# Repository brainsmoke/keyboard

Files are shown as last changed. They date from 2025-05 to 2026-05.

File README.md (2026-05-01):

# A numpad-less keyboard with back lighting

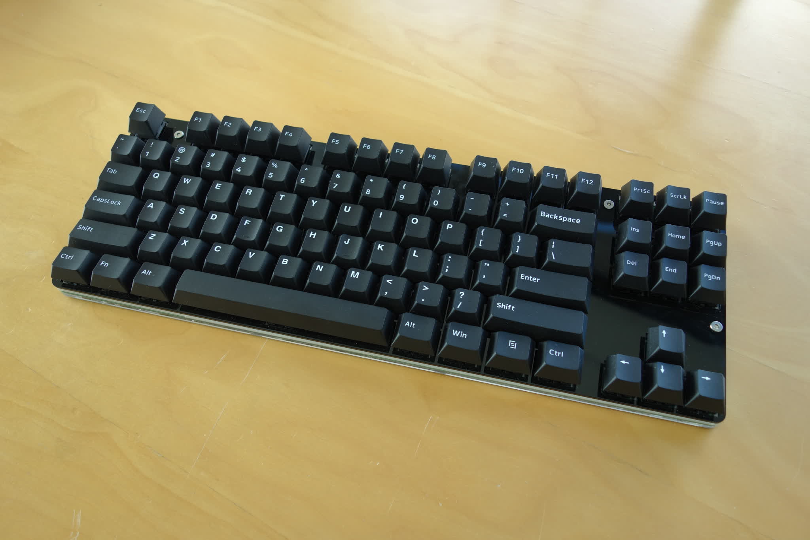
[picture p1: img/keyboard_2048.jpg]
Photo of the completed keyboard, an '80%' layout, the PCB is sandwiched in between a few layers of acrylic


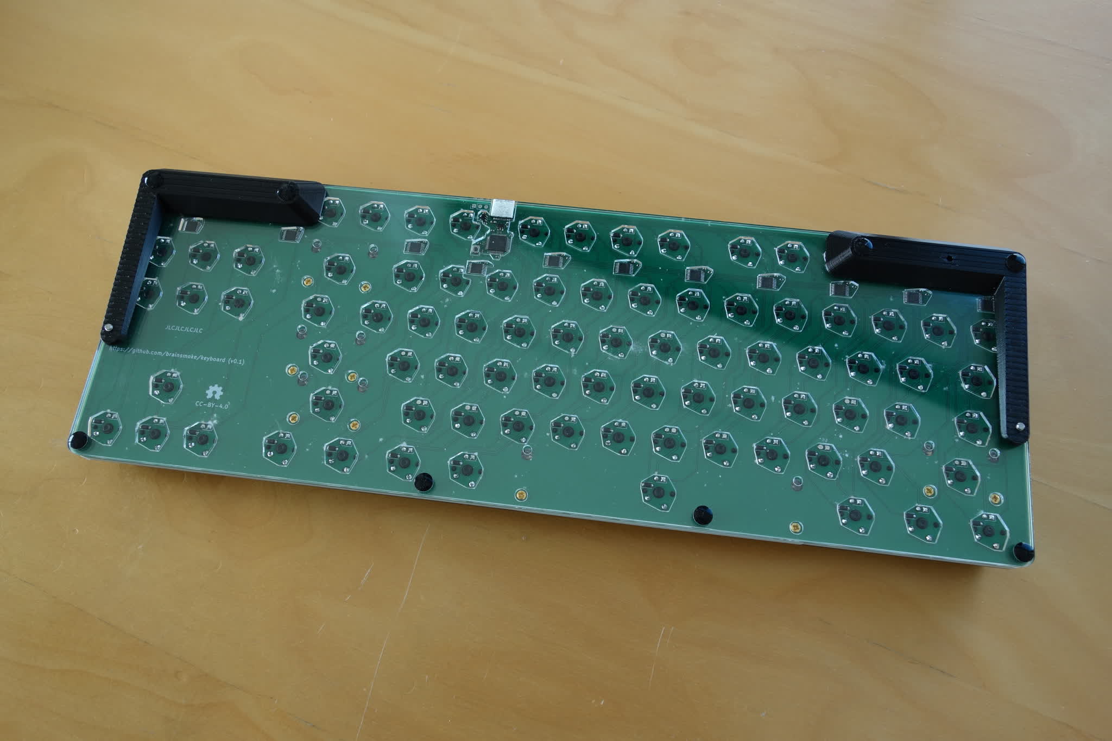
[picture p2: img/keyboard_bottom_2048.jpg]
Photo of the bottom side of the keyboard, the bottom is covered in transparant acrylic, exposing the circuit & chips


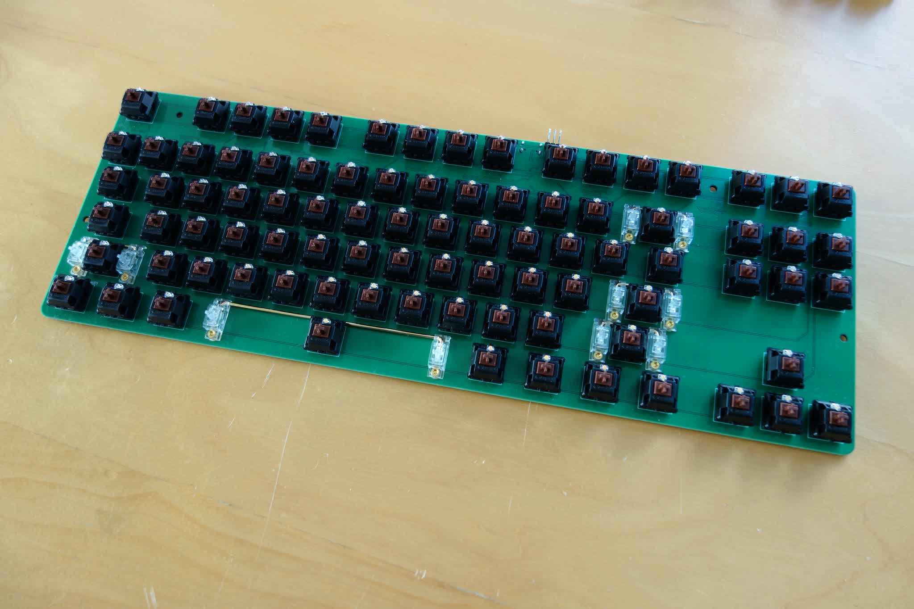
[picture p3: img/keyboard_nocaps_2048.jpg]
Photo of the keyboard without keycaps, exposing the cherry style keys


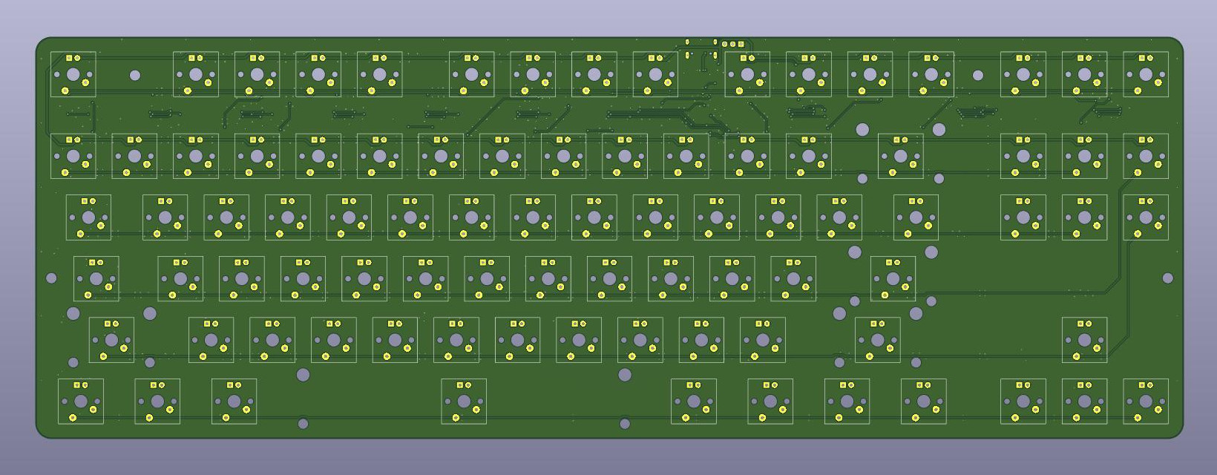
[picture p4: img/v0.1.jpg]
Image of a keyboard PCB


TODO: find keycaps which look good with AND without backlight

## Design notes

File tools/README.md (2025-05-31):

```
apt install python3-venv
python3 -m venv --system-site-packages venv ;. venv/bin/activate
pip3 install kicad-python

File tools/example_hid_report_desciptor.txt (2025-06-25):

Usage Page (Generic Desktop)
Usage (Keypad)
Collection (Application)
Usage Page (Keyboard)

Usage (Generic Desktop, System Sleep)
Usage (Generic Desktop, System Wake Up)
Usage (Generic Desktop, System Power Down)
Usage (Generic Desktop, System Warm Restart)

Usage (Consumer, Play)
Usage (Consumer, Pause)
Usage (Consumer, Stop)
Usage (Consumer, Record)

Usage (Consumer, Rewind)
Usage (Consumer, Fast Forward)
Usage (Consumer, Scan Previous Track)
Usage (Consumer, Scan Next Track)

Usage (Keyboard, Volume Down)
Usage (Keyboard, Volume Up)
Usage (Consumer, AL Calculator)
Usage (Keyboard, 0x04)

Report Size (1)
Report Count (16)
Input (Data, Variable, Absolute)

Report Size (8)
Report Count (1)
Input (Constant)

End Collection

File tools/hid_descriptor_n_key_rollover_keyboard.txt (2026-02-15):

Usage Page (Generic Desktop)
Usage (Keyboard)
Collection (Application)
  Report Size (1)
  Report Count (8)
  Usage Page (Keyboard)
  Usage Minimum (224)
  Usage Maximum (231)
  Logical Minimum (0)
  Logical Maximum (1)
  Input (Data, Variable, Absolute)
  Report Count (1)
  Report Size (8)
  Input (Constant)
  Report Count (5)
  Report Size (1)
  Usage Page (LED)
  Usage Minimum (1)
  Usage Maximum (5)
  Output (Data, Variable, Absolute)
  Report Count (1)
  Report Size (3)
  Output (Constant)
  Report Count (6)
  Report Size (8)
#  Logical Minimum (0)
#  Logical Maximum(255)
#  Usage Page (Keyboard)
#  Usage Minimum (0)
#  Usage Maximum (255)
#  Input (Data, Array)
  Input (Constant)
  Usage Page (Keyboard)
  Report Size (1)
  Report Count (79)
  Usage Minimum (4)
  Usage Maximum (82)
  Input (Data, Variable, Absolute)
End Collection

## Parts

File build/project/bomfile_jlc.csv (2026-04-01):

Comment | Designator | Footprint | JLCPCB Part #
1uF | C1,C2,C3,C4,C10 | Capacitor_SMD:C_0402_1005Metric | C52923
100nF | C5,C6,C7,C8,C9,C11,C12,C13,C14,C15,C16,C17 | Capacitor_SMD:C_0402_1005Metric | C1525
d_0,d_1,d_2,d_3,d_4,d_5,d_6,d_7,d_8,d_9,d_a,d_alt,d_altgr,d_b,d_backslash,d_backspace,d_c,d_capslock,d_closebracket,d_comma,d_d,d_delete,d_dot,d_down,d_e,d_end,d_enter,d_equals,d_esc,d_f,d_f1,d_f10,d_f11,d_f12,d_f2,d_f3,d_f4,d_f5,d_f6,d_f7,d_f8,d_f9,d_fn,d_g,d_h,d_home,d_i,d_insert,d_j,d_k,d_l,d_left,d_leftcontrol,d_leftshift,d_m,d_menu,d_minus,d_n,d_o,d_openbracket,d_p,d_pagedown,d_pageup,d_pause,d_printscreen,d_q,d_quote,d_r,d_right,d_rightcontrol,d_rightshift,d_s,d_scrollock,d_semicolon,d_slash,d_space,d_t,d_tab,d_tilde,d_u,d_up,d_v,d_w,d_win,d_x,d_y,d_z | D1,D2,D3,D4,D5,D6,D7,D8,D9,D10,D11,D12,D13,D14,D15,D16,D17,D18,D19,D20,D21,D22,D23,D24,D25,D26,D27,D28,D29,D30,D31,D32,D33,D34,D35,D36,D37,D38,D39,D40,D41,D42,D43,D44,D45,D46,D47,D48,D49,D50,D51,D52,D53,D54,D55,D56,D57,D58,D59,D60,D61,D62,D63,D64,D65,D66,D67,D68,D69,D70,D71,D72,D73,D74,D75,D76,D77,D78,D79,D80,D81,D82,D83,D84,D85,D86,D87 | Diode_SMD:D_SOD-123 | C81598
USB_C_Receptacle_USB2.0 | J1 | footprints:USB_C_Receptacle_HRO_TYPE-C-31-M-12 | C165948
100k | R1,R4 | Resistor_SMD:R_0402_1005Metric | C25741
5k1,REXT_0,REXT_1,REXT_10,REXT_2,REXT_3,REXT_4,REXT_5,REXT_6,REXT_7,REXT_8,REXT_9 | R2,R3,R5,R6,R7,R8,R9,R10,R11,R12,R13,R14,R15 | Resistor_SMD:R_0402_1005Metric | C25905
SW_SPST | SW88 | Button_Switch_SMD:SW_Push_1P1T_NO_CK_KMR2 | C318893
USBLC6-2SC6 | U1 | Package_TO_SOT_SMD:SOT-23-6 | C7519
STM32F072C8Tx | U2 | Package_QFP:LQFP-48_7x7mm_P0.5mm | C81720
AP2112K-3.3 | U3 | Package_TO_SOT_SMD:SOT-23-5 | C51118
TLC5916_0,TLC5916_1,TLC5916_10,TLC5916_2,TLC5916_3,TLC5916_4,TLC5916_5,TLC5916_6,TLC5916_7,TLC5916_8,TLC5916_9 | U4,U5,U6,U7,U8,U9,U10,U11,U12,U13,U14 | Package_SO:TSSOP-16_4.4x5mm_P0.65mm | C2678539

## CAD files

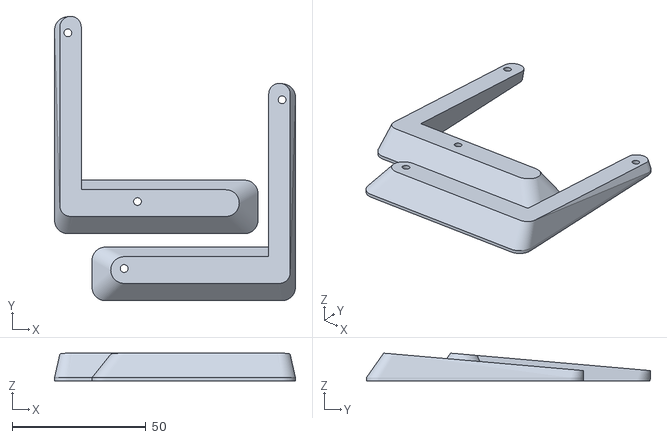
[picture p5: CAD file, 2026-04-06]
case/feet_upside_down.stl
90.0 x 106.2 x 10.4

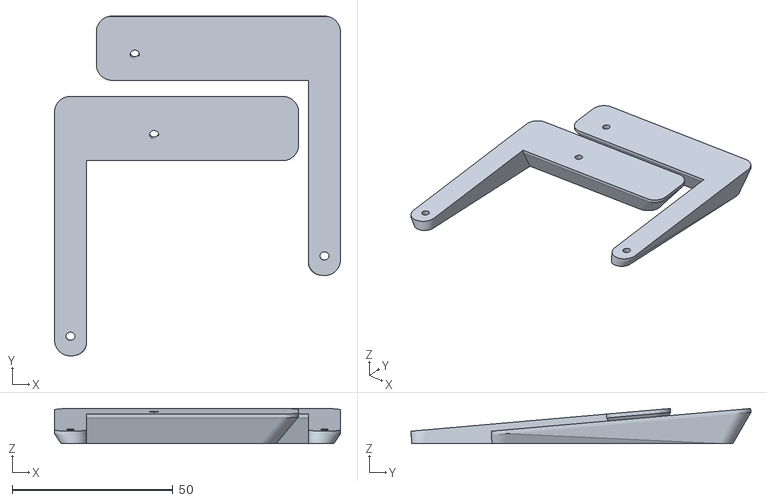
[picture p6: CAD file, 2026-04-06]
case/feet_print_right_side_up.stl
89.0 x 105.8 x 10.9

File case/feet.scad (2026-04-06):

e=.001;
$fn=48;
padding=5;

dim = [ 357, 125, 10 ] ;

holes = [ [31, dim.y-12], [dim.x-64, dim.y-12], [ 5, 50 ], [dim.x-5, 50 ] ] ;

r = 5;

bottom = 1.2;
screw_hole_d = 2.9;

angle = 5;

module do_center(dim, center)
{
    if (center)
        translate(-dim/2)
            children();
    else
        children();
}
 
module rounded_box(dim, r, center=false)
{
    do_center(dim, center)
    hull()
    {
        for (x=[r,dim.x-r])
        for (y=[r,dim.y-r])
        translate([x,y,0])
        cylinder(h=dim.z,r=r);
    }
}

module preview()
{
	if ($preview) children();
}


module at_holes()
{
	for (pos=holes)
        translate([pos.x, pos.y, 0])
            children();
}

module reflect_x(x)
{
	translate([x,0,0])
	scale([-1,1,1])
	translate([-x,0,0])
	children();
}

module mirror_x(x)
{
	children();
	reflect_x(x)
	children();
}


module feet()
{

	difference()
	{
	union()
	{
		mirror_x(dim.x/2)
		hull()
		{
		rotate([-angle,0,0])
		translate([2,dim.y-16,0])
		rounded_box([67, 10, bottom], 5);
		translate([0,dim.y-20,-bottom])
		rounded_box([76, 20, bottom], r);
		}

		mirror_x(dim.x/2)
		hull()
		{
		rotate([-angle,0,0])
		translate([2,dim.y-81,0])
		rounded_box([8, 75, bottom], 4);
		translate([0,dim.y-81,-bottom])
		rounded_box([10, 81, bottom], r);
		}
	}

	at_holes() translate([0,0,-20+e]) cylinder(d=screw_hole_d, h=20);
	}
}

module left_foot()
{
	intersection()
	{
	translate([-5,-5,-25])
	cube([dim.x/2+5,dim.y+10, 30]);
	feet();
	}
}


module right_foot()
{
	intersection()
	{
	reflect_x(dim.x/2)
	translate([-5,-5,-25])
	cube([dim.x/2+5,dim.y+10, 30]);
	feet();
	}
}

preview()
{
left_foot();
right_foot();
}

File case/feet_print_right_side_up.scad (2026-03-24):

use <feet.scad>;


translate([0,-43,0])
{
rotate( [5,0,0] )
left_foot();

translate([-268,25,0])
rotate( [5,0,0] )
right_foot();
}

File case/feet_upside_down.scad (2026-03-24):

use <feet.scad>;

translate([0,150,0])
rotate([180,0,0])
{
left_foot();

translate([-267,25,0])
right_foot();
}

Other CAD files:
case/usb.scad

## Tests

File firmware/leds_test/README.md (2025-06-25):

# idoing pcb tests before I solder all my mx keys

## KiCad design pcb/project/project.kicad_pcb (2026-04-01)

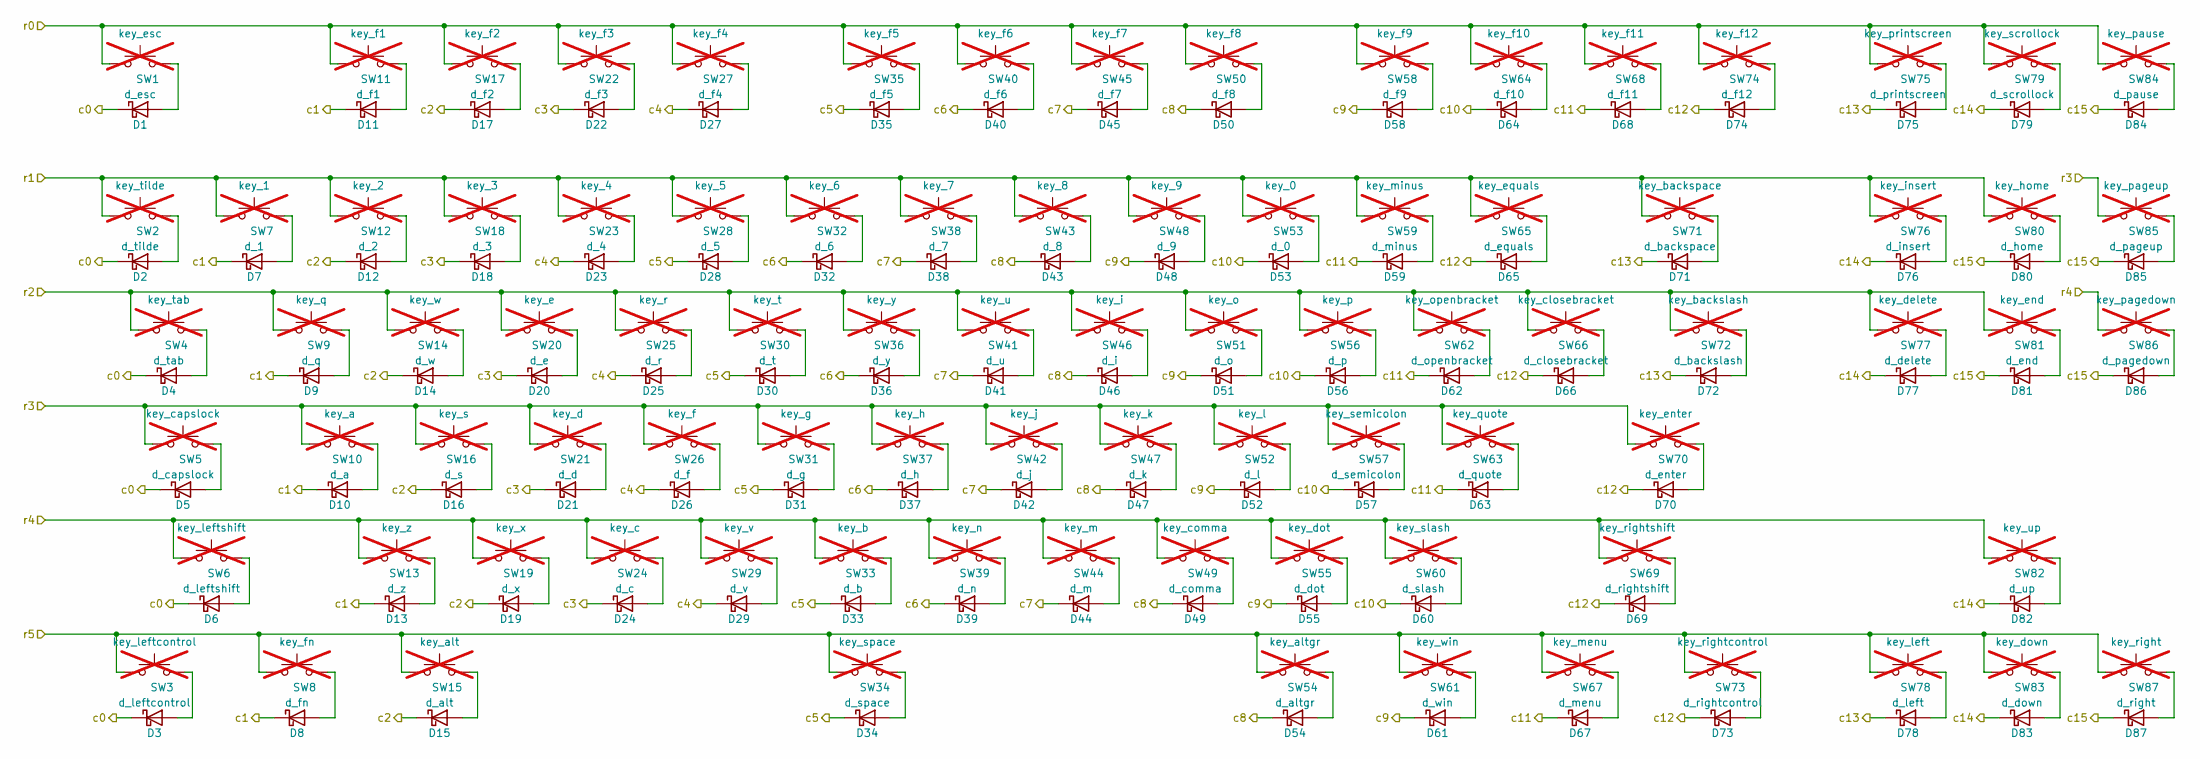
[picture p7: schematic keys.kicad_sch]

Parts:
D1: d_esc; D_SOD-123; LCSC C81598
D2: d_tilde; D_SOD-123; LCSC C81598
D3: d_leftcontrol; D_SOD-123; LCSC C81598
D4: d_tab; D_SOD-123; LCSC C81598
D5: d_capslock; D_SOD-123; LCSC C81598
D6: d_leftshift; D_SOD-123; LCSC C81598
D7: d_1; D_SOD-123; LCSC C81598
D8: d_fn; D_SOD-123; LCSC C81598
D9: d_q; D_SOD-123; LCSC C81598
D10: d_a; D_SOD-123; LCSC C81598
D11: d_f1; D_SOD-123; LCSC C81598
D12: d_2; D_SOD-123; LCSC C81598
D13: d_z; D_SOD-123; LCSC C81598
D14: d_w; D_SOD-123; LCSC C81598
D15: d_alt; D_SOD-123; LCSC C81598
D16: d_s; D_SOD-123; LCSC C81598
D17: d_f2; D_SOD-123; LCSC C81598
D18: d_3; D_SOD-123; LCSC C81598
D19: d_x; D_SOD-123; LCSC C81598
D20: d_e; D_SOD-123; LCSC C81598
D21: d_d; D_SOD-123; LCSC C81598
D22: d_f3; D_SOD-123; LCSC C81598
D23: d_4; D_SOD-123; LCSC C81598
D24: d_c; D_SOD-123; LCSC C81598
D25: d_r; D_SOD-123; LCSC C81598
D26: d_f; D_SOD-123; LCSC C81598
D27: d_f4; D_SOD-123; LCSC C81598
D28: d_5; D_SOD-123; LCSC C81598
D29: d_v; D_SOD-123; LCSC C81598
D30: d_t; D_SOD-123; LCSC C81598
D31: d_g; D_SOD-123; LCSC C81598
D32: d_6; D_SOD-123; LCSC C81598
D33: d_b; D_SOD-123; LCSC C81598
D34: d_space; D_SOD-123; LCSC C81598
D35: d_f5; D_SOD-123; LCSC C81598
D36: d_y; D_SOD-123; LCSC C81598
D37: d_h; D_SOD-123; LCSC C81598
D38: d_7; D_SOD-123; LCSC C81598
D39: d_n; D_SOD-123; LCSC C81598
D40: d_f6; D_SOD-123; LCSC C81598
D41: d_u; D_SOD-123; LCSC C81598
D42: d_j; D_SOD-123; LCSC C81598
D43: d_8; D_SOD-123; LCSC C81598
D44: d_m; D_SOD-123; LCSC C81598
D45: d_f7; D_SOD-123; LCSC C81598
D46: d_i; D_SOD-123; LCSC C81598
D47: d_k; D_SOD-123; LCSC C81598
D48: d_9; D_SOD-123; LCSC C81598
D49: d_comma; D_SOD-123; LCSC C81598
D50: d_f8; D_SOD-123; LCSC C81598
D51: d_o; D_SOD-123; LCSC C81598
D52: d_l; D_SOD-123; LCSC C81598
D53: d_0; D_SOD-123; LCSC C81598
D54: d_altgr; D_SOD-123; LCSC C81598
D55: d_dot; D_SOD-123; LCSC C81598
D56: d_p; D_SOD-123; LCSC C81598
D57: d_semicolon; D_SOD-123; LCSC C81598
D58: d_f9; D_SOD-123; LCSC C81598
D59: d_minus; D_SOD-123; LCSC C81598
D60: d_slash; D_SOD-123; LCSC C81598
D61: d_win; D_SOD-123; LCSC C81598
D62: d_openbracket; D_SOD-123; LCSC C81598
D63: d_quote; D_SOD-123; LCSC C81598
D64: d_f10; D_SOD-123; LCSC C81598
D65: d_equals; D_SOD-123; LCSC C81598
D66: d_closebracket; D_SOD-123; LCSC C81598
D67: d_menu; D_SOD-123; LCSC C81598
D68: d_f11; D_SOD-123; LCSC C81598
D69: d_rightshift; D_SOD-123; LCSC C81598
D70: d_enter; D_SOD-123; LCSC C81598
D71: d_backspace; D_SOD-123; LCSC C81598
D72: d_backslash; D_SOD-123; LCSC C81598
D73: d_rightcontrol; D_SOD-123; LCSC C81598
D74: d_f12; D_SOD-123; LCSC C81598
D75: d_printscreen; D_SOD-123; LCSC C81598
D76: d_insert; D_SOD-123; LCSC C81598
D77: d_delete; D_SOD-123; LCSC C81598
D78: d_left; D_SOD-123; LCSC C81598
D79: d_scrollock; D_SOD-123; LCSC C81598
D80: d_home; D_SOD-123; LCSC C81598
D81: d_end; D_SOD-123; LCSC C81598
D82: d_up; D_SOD-123; LCSC C81598
D83: d_down; D_SOD-123; LCSC C81598
D84: d_pause; D_SOD-123; LCSC C81598
D85: d_pageup; D_SOD-123; LCSC C81598
D86: d_pagedown; D_SOD-123; LCSC C81598
D87: d_right; D_SOD-123; LCSC C81598
SW1: key_esc; SW_Cherry_MX_1.00u_PCB; not fitted
SW2: key_tilde; SW_Cherry_MX_1.00u_PCB; not fitted
SW3: key_leftcontrol; SW_Cherry_MX_1.25u_PCB; not fitted
SW4: key_tab; SW_Cherry_MX_1.50u_PCB; not fitted
SW5: key_capslock; SW_Cherry_MX_1.75u_PCB; not fitted
SW6: key_leftshift; SW_Cherry_MX_2.25u_PCB; not fitted
SW7: key_1; SW_Cherry_MX_1.00u_PCB; not fitted
SW8: key_fn; SW_Cherry_MX_1.25u_PCB; not fitted
SW9: key_q; SW_Cherry_MX_1.00u_PCB; not fitted
SW10: key_a; SW_Cherry_MX_1.00u_PCB; not fitted
SW11: key_f1; SW_Cherry_MX_1.00u_PCB; not fitted
SW12: key_2; SW_Cherry_MX_1.00u_PCB; not fitted
SW13: key_z; SW_Cherry_MX_1.00u_PCB; not fitted
SW14: key_w; SW_Cherry_MX_1.00u_PCB; not fitted
SW15: key_alt; SW_Cherry_MX_1.25u_PCB; not fitted
SW16: key_s; SW_Cherry_MX_1.00u_PCB; not fitted
SW17: key_f2; SW_Cherry_MX_1.00u_PCB; not fitted
SW18: key_3; SW_Cherry_MX_1.00u_PCB; not fitted
SW19: key_x; SW_Cherry_MX_1.00u_PCB; not fitted
SW20: key_e; SW_Cherry_MX_1.00u_PCB; not fitted
SW21: key_d; SW_Cherry_MX_1.00u_PCB; not fitted
SW22: key_f3; SW_Cherry_MX_1.00u_PCB; not fitted
SW23: key_4; SW_Cherry_MX_1.00u_PCB; not fitted
SW24: key_c; SW_Cherry_MX_1.00u_PCB; not fitted
SW25: key_r; SW_Cherry_MX_1.00u_PCB; not fitted
SW26: key_f; SW_Cherry_MX_1.00u_PCB; not fitted
SW27: key_f4; SW_Cherry_MX_1.00u_PCB; not fitted
SW28: key_5; SW_Cherry_MX_1.00u_PCB; not fitted
SW29: key_v; SW_Cherry_MX_1.00u_PCB; not fitted
SW30: key_t; SW_Cherry_MX_1.00u_PCB; not fitted
SW31: key_g; SW_Cherry_MX_1.00u_PCB; not fitted
SW32: key_6; SW_Cherry_MX_1.00u_PCB; not fitted
SW33: key_b; SW_Cherry_MX_1.00u_PCB; not fitted
SW34: key_space; SW_Cherry_MX_6.25u_PCB; not fitted
SW35: key_f5; SW_Cherry_MX_1.00u_PCB; not fitted
SW36: key_y; SW_Cherry_MX_1.00u_PCB; not fitted
SW37: key_h; SW_Cherry_MX_1.00u_PCB; not fitted
SW38: key_7; SW_Cherry_MX_1.00u_PCB; not fitted
SW39: key_n; SW_Cherry_MX_1.00u_PCB; not fitted
SW40: key_f6; SW_Cherry_MX_1.00u_PCB; not fitted
SW41: key_u; SW_Cherry_MX_1.00u_PCB; not fitted
SW42: key_j; SW_Cherry_MX_1.00u_PCB; not fitted
SW43: key_8; SW_Cherry_MX_1.00u_PCB; not fitted
SW44: key_m; SW_Cherry_MX_1.00u_PCB; not fitted
SW45: key_f7; SW_Cherry_MX_1.00u_PCB; not fitted
SW46: key_i; SW_Cherry_MX_1.00u_PCB; not fitted
SW47: key_k; SW_Cherry_MX_1.00u_PCB; not fitted
SW48: key_9; SW_Cherry_MX_1.00u_PCB; not fitted
SW49: key_comma; SW_Cherry_MX_1.00u_PCB; not fitted
SW50: key_f8; SW_Cherry_MX_1.00u_PCB; not fitted
SW51: key_o; SW_Cherry_MX_1.00u_PCB; not fitted
SW52: key_l; SW_Cherry_MX_1.00u_PCB; not fitted
SW53: key_0; SW_Cherry_MX_1.00u_PCB; not fitted
SW54: key_altgr; SW_Cherry_MX_1.25u_PCB; not fitted
SW55: key_dot; SW_Cherry_MX_1.00u_PCB; not fitted
SW56: key_p; SW_Cherry_MX_1.00u_PCB; not fitted
SW57: key_semicolon; SW_Cherry_MX_1.00u_PCB; not fitted
SW58: key_f9; SW_Cherry_MX_1.00u_PCB; not fitted
SW59: key_minus; SW_Cherry_MX_1.00u_PCB; not fitted
SW60: key_slash; SW_Cherry_MX_1.00u_PCB; not fitted
SW61: key_win; SW_Cherry_MX_1.25u_PCB; not fitted
SW62: key_openbracket; SW_Cherry_MX_1.00u_PCB; not fitted
SW63: key_quote; SW_Cherry_MX_1.00u_PCB; not fitted
SW64: key_f10; SW_Cherry_MX_1.00u_PCB; not fitted
SW65: key_equals; SW_Cherry_MX_1.00u_PCB; not fitted
SW66: key_closebracket; SW_Cherry_MX_1.00u_PCB; not fitted
SW67: key_menu; SW_Cherry_MX_1.25u_PCB; not fitted
SW68: key_f11; SW_Cherry_MX_1.00u_PCB; not fitted
SW69: key_rightshift; SW_Cherry_MX_2.75u_PCB; not fitted
SW70: key_enter; SW_Cherry_MX_2.25u_PCB; not fitted
SW71: key_backspace; SW_Cherry_MX_2.00u_PCB; not fitted
SW72: key_backslash; SW_Cherry_MX_1.50u_PCB; not fitted
SW73: key_rightcontrol; SW_Cherry_MX_1.25u_PCB; not fitted
SW74: key_f12; SW_Cherry_MX_1.00u_PCB; not fitted
SW75: key_printscreen; SW_Cherry_MX_1.00u_PCB; not fitted
SW76: key_insert; SW_Cherry_MX_1.00u_PCB; not fitted
SW77: key_delete; SW_Cherry_MX_1.00u_PCB; not fitted
SW78: key_left; SW_Cherry_MX_1.00u_PCB; not fitted
SW79: key_scrollock; SW_Cherry_MX_1.00u_PCB; not fitted
SW80: key_home; SW_Cherry_MX_1.00u_PCB; not fitted
SW81: key_end; SW_Cherry_MX_1.00u_PCB; not fitted
SW82: key_up; SW_Cherry_MX_1.00u_PCB; not fitted
SW83: key_down; SW_Cherry_MX_1.00u_PCB; not fitted
SW84: key_pause; SW_Cherry_MX_1.00u_PCB; not fitted
SW85: key_pageup; SW_Cherry_MX_1.00u_PCB; not fitted
SW86: key_pagedown; SW_Cherry_MX_1.00u_PCB; not fitted
SW87: key_right; SW_Cherry_MX_1.00u_PCB; not fitted

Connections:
/C0: D1.1 (K), D2.1 (K), D3.1 (K), D4.1 (K), D5.1 (K), D6.1 (K); also elsewhere on the board
/C1: D7.1 (K), D8.1 (K), D9.1 (K), D10.1 (K), D11.1 (K), D13.1 (K); also elsewhere on the board
/C2: D12.1 (K), D14.1 (K), D15.1 (K), D16.1 (K), D17.1 (K), D19.1 (K); also elsewhere on the board
/C3: D18.1 (K), D20.1 (K), D21.1 (K), D22.1 (K), D24.1 (K); also elsewhere on the board
/C4: D23.1 (K), D25.1 (K), D26.1 (K), D27.1 (K), D29.1 (K); also elsewhere on the board
/C5: D28.1 (K), D30.1 (K), D31.1 (K), D33.1 (K), D34.1 (K), D35.1 (K); also elsewhere on the board
/C6: D32.1 (K), D36.1 (K), D37.1 (K), D39.1 (K), D40.1 (K); also elsewhere on the board
/C7: D38.1 (K), D41.1 (K), D42.1 (K), D44.1 (K), D45.1 (K); also elsewhere on the board
/C8: D43.1 (K), D46.1 (K), D47.1 (K), D49.1 (K), D50.1 (K), D54.1 (K); also elsewhere on the board
/C9: D48.1 (K), D51.1 (K), D52.1 (K), D55.1 (K), D58.1 (K), D61.1 (K); also elsewhere on the board
/C10: D53.1 (K), D56.1 (K), D57.1 (K), D60.1 (K), D64.1 (K); also elsewhere on the board
/C11: D59.1 (K), D62.1 (K), D63.1 (K), D67.1 (K), D68.1 (K); also elsewhere on the board
/C12: D65.1 (K), D66.1 (K), D69.1 (K), D70.1 (K), D73.1 (K), D74.1 (K); also elsewhere on the board
/C13: D71.1 (K), D72.1 (K), D75.1 (K), D78.1 (K); also elsewhere on the board
/C14: D76.1 (K), D77.1 (K), D79.1 (K), D82.1 (K), D83.1 (K); also elsewhere on the board
/C15: D80.1 (K), D81.1 (K), D84.1 (K), D85.1 (K), D86.1 (K), D87.1 (K); also elsewhere on the board
/R0: SW1.1, SW11.1, SW17.1, SW22.1, SW27.1, SW35.1, SW40.1, SW45.1, SW50.1, SW58.1, SW64.1, SW68.1, SW74.1, SW75.1, SW79.1, SW84.1; also elsewhere on the board
/R1: SW2.1, SW7.1, SW12.1, SW18.1, SW23.1, SW28.1, SW32.1, SW38.1, SW43.1, SW48.1, SW53.1, SW59.1, SW65.1, SW71.1, SW76.1, SW80.1; also elsewhere on the board
/R2: SW4.1, SW9.1, SW14.1, SW20.1, SW25.1, SW30.1, SW36.1, SW41.1, SW46.1, SW51.1, SW56.1, SW62.1, SW66.1, SW72.1, SW77.1, SW81.1; also elsewhere on the board
/R3: SW5.1, SW10.1, SW16.1, SW21.1, SW26.1, SW31.1, SW37.1, SW42.1, SW47.1, SW52.1, SW57.1, SW63.1, SW70.1, SW85.1; also elsewhere on the board
/R4: SW6.1, SW13.1, SW19.1, SW24.1, SW29.1, SW33.1, SW39.1, SW44.1, SW49.1, SW55.1, SW60.1, SW69.1, SW82.1, SW86.1; also elsewhere on the board
/R5: SW3.1, SW8.1, SW15.1, SW34.1, SW54.1, SW61.1, SW67.1, SW73.1, SW78.1, SW83.1, SW87.1; also elsewhere on the board
unnamed: D1.2 (A), SW1.2
unnamed: D2.2 (A), SW2.2
unnamed: D3.2 (A), SW3.2
unnamed: D4.2 (A), SW4.2
unnamed: D5.2 (A), SW5.2
unnamed: D6.2 (A), SW6.2
unnamed: D7.2 (A), SW7.2
unnamed: D8.2 (A), SW8.2
unnamed: D9.2 (A), SW9.2
unnamed: D10.2 (A), SW10.2
unnamed: D11.2 (A), SW11.2
unnamed: D12.2 (A), SW12.2
unnamed: D13.2 (A), SW13.2
unnamed: D14.2 (A), SW14.2
unnamed: D15.2 (A), SW15.2
unnamed: D16.2 (A), SW16.2
unnamed: D17.2 (A), SW17.2
unnamed: D18.2 (A), SW18.2
unnamed: D19.2 (A), SW19.2
unnamed: D20.2 (A), SW20.2
unnamed: D21.2 (A), SW21.2
unnamed: D22.2 (A), SW22.2
unnamed: D23.2 (A), SW23.2
unnamed: D24.2 (A), SW24.2
unnamed: D25.2 (A), SW25.2
unnamed: D26.2 (A), SW26.2
unnamed: D27.2 (A), SW27.2
unnamed: D28.2 (A), SW28.2
unnamed: D29.2 (A), SW29.2
unnamed: D30.2 (A), SW30.2
unnamed: D31.2 (A), SW31.2
unnamed: D32.2 (A), SW32.2
unnamed: D33.2 (A), SW33.2
unnamed: D34.2 (A), SW34.2
unnamed: D35.2 (A), SW35.2
unnamed: D36.2 (A), SW36.2
unnamed: D37.2 (A), SW37.2
unnamed: D38.2 (A), SW38.2
unnamed: D39.2 (A), SW39.2
unnamed: D40.2 (A), SW40.2
unnamed: D41.2 (A), SW41.2
unnamed: D42.2 (A), SW42.2
unnamed: D43.2 (A), SW43.2
unnamed: D44.2 (A), SW44.2
unnamed: D45.2 (A), SW45.2
unnamed: D46.2 (A), SW46.2
unnamed: D47.2 (A), SW47.2
unnamed: D48.2 (A), SW48.2
unnamed: D49.2 (A), SW49.2
unnamed: D50.2 (A), SW50.2
unnamed: D51.2 (A), SW51.2
unnamed: D52.2 (A), SW52.2
unnamed: D53.2 (A), SW53.2
unnamed: D54.2 (A), SW54.2
unnamed: D55.2 (A), SW55.2
unnamed: D56.2 (A), SW56.2
unnamed: D57.2 (A), SW57.2
unnamed: D58.2 (A), SW58.2
unnamed: D59.2 (A), SW59.2
unnamed: D60.2 (A), SW60.2
unnamed: D61.2 (A), SW61.2
unnamed: D62.2 (A), SW62.2
unnamed: D63.2 (A), SW63.2
unnamed: D64.2 (A), SW64.2
unnamed: D65.2 (A), SW65.2
unnamed: D66.2 (A), SW66.2
unnamed: D67.2 (A), SW67.2
unnamed: D68.2 (A), SW68.2
unnamed: D69.2 (A), SW69.2
unnamed: D70.2 (A), SW70.2
unnamed: D71.2 (A), SW71.2
unnamed: D72.2 (A), SW72.2
unnamed: D73.2 (A), SW73.2
unnamed: D74.2 (A), SW74.2
unnamed: D75.2 (A), SW75.2
unnamed: D76.2 (A), SW76.2
unnamed: D77.2 (A), SW77.2
unnamed: D78.2 (A), SW78.2
unnamed: D79.2 (A), SW79.2
unnamed: D80.2 (A), SW80.2
unnamed: D81.2 (A), SW81.2
unnamed: D82.2 (A), SW82.2
unnamed: D83.2 (A), SW83.2
unnamed: D84.2 (A), SW84.2
unnamed: D85.2 (A), SW85.2
unnamed: D86.2 (A), SW86.2
unnamed: D87.2 (A), SW87.2

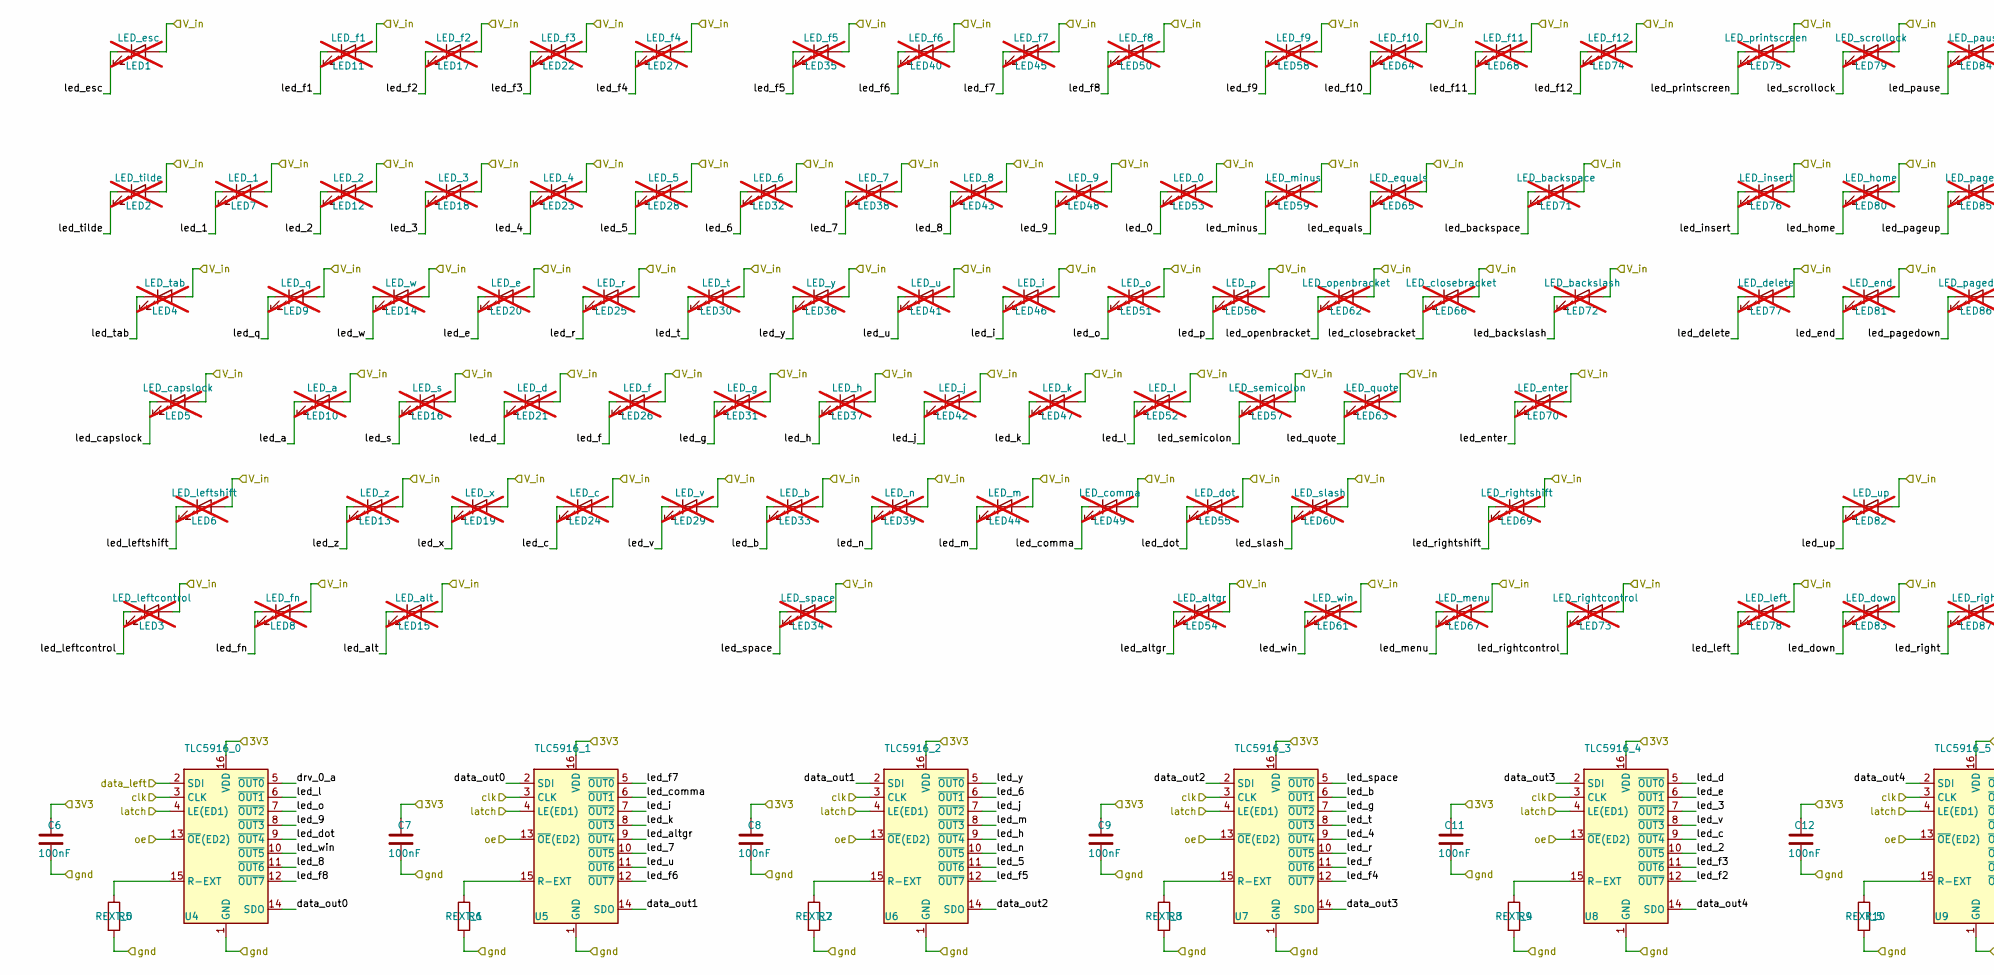
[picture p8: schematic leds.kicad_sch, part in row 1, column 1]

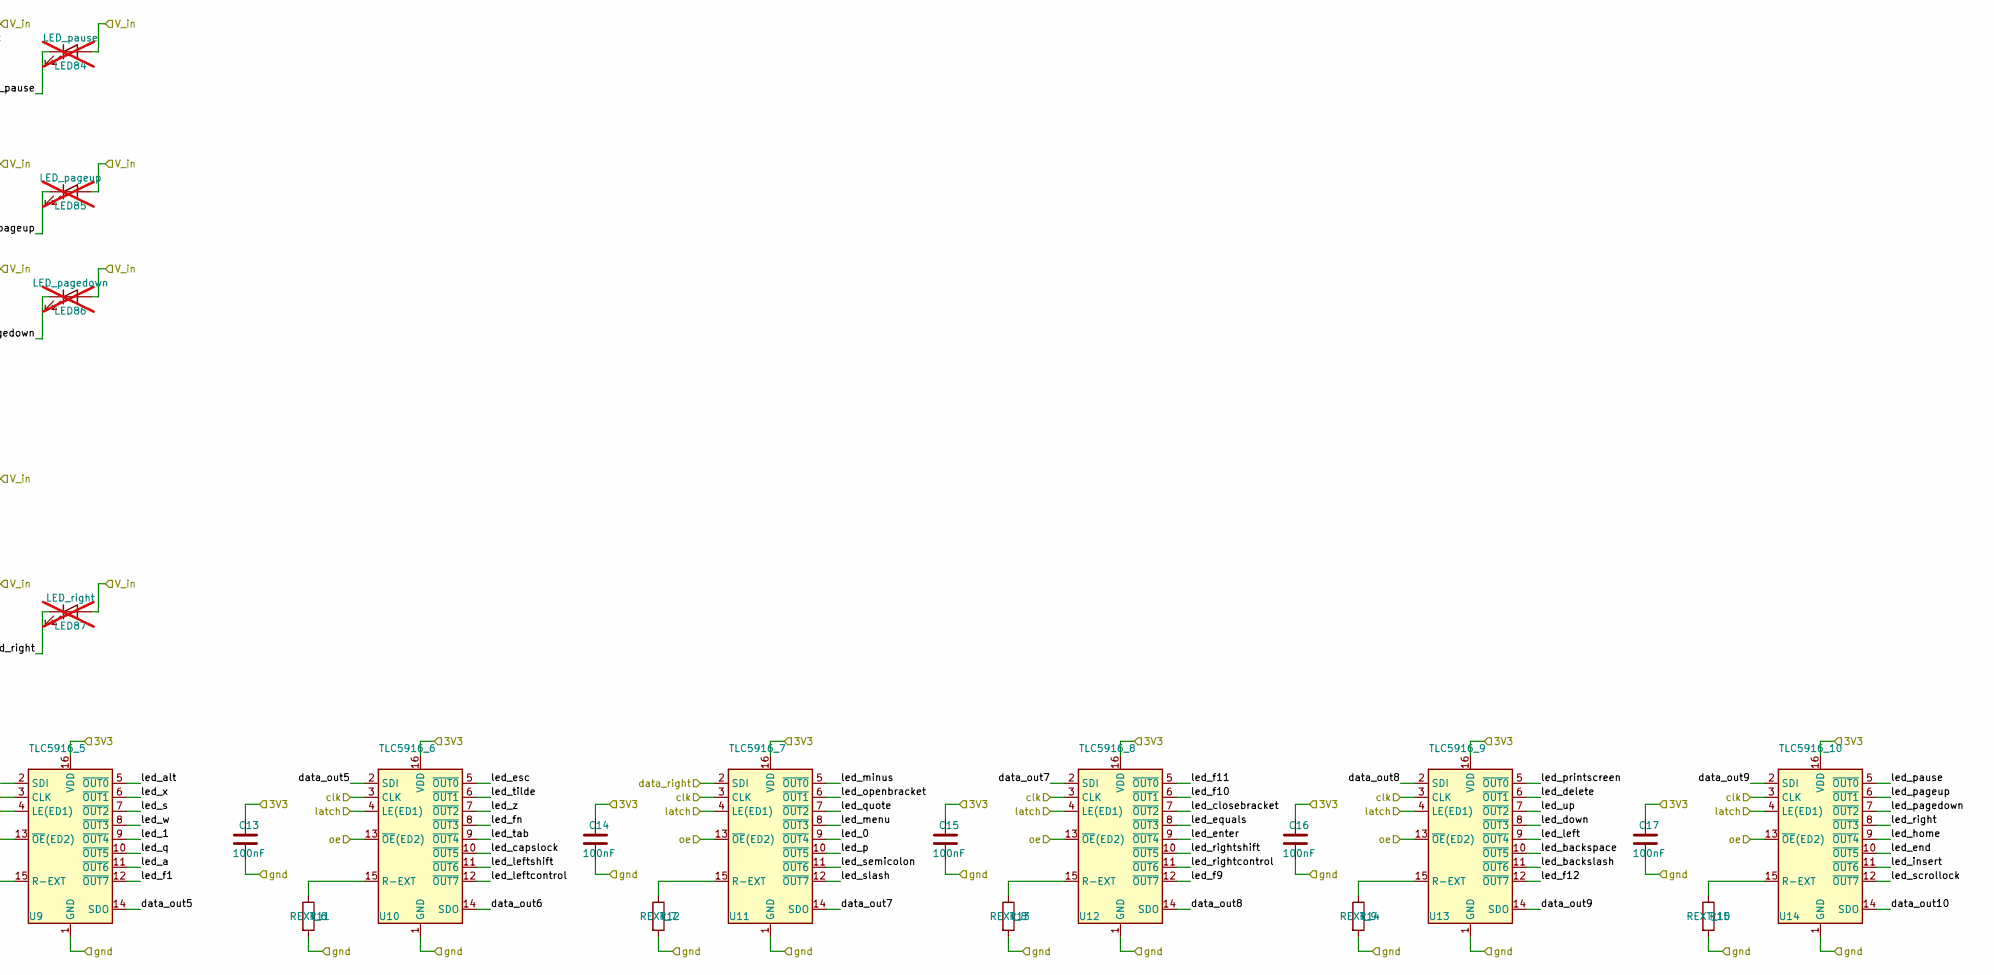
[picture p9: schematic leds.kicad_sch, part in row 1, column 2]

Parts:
C6, C7, C8, C9, C11, C12, C13, C14, C15, C16, C17: 100nF; C_0402_1005Metric; LCSC C1525
LED1: LED_esc; LED3mm; not fitted
LED2: LED_tilde; LED3mm; not fitted
LED3: LED_leftcontrol; LED3mm; not fitted
LED4: LED_tab; LED3mm; not fitted
LED5: LED_capslock; LED3mm; not fitted
LED6: LED_leftshift; LED3mm; not fitted
LED7: LED_1; LED3mm; not fitted
LED8: LED_fn; LED3mm; not fitted
LED9: LED_q; LED3mm; not fitted
LED10: LED_a; LED3mm; not fitted
LED11: LED_f1; LED3mm; not fitted
LED12: LED_2; LED3mm; not fitted
LED13: LED_z; LED3mm; not fitted
LED14: LED_w; LED3mm; not fitted
LED15: LED_alt; LED3mm; not fitted
LED16: LED_s; LED3mm; not fitted
LED17: LED_f2; LED3mm; not fitted
LED18: LED_3; LED3mm; not fitted
LED19: LED_x; LED3mm; not fitted
LED20: LED_e; LED3mm; not fitted
LED21: LED_d; LED3mm; not fitted
LED22: LED_f3; LED3mm; not fitted
LED23: LED_4; LED3mm; not fitted
LED24: LED_c; LED3mm; not fitted
LED25: LED_r; LED3mm; not fitted
LED26: LED_f; LED3mm; not fitted
LED27: LED_f4; LED3mm; not fitted
LED28: LED_5; LED3mm; not fitted
LED29: LED_v; LED3mm; not fitted
LED30: LED_t; LED3mm; not fitted
LED31: LED_g; LED3mm; not fitted
LED32: LED_6; LED3mm; not fitted
LED33: LED_b; LED3mm; not fitted
LED34: LED_space; LED3mm; not fitted
LED35: LED_f5; LED3mm; not fitted
LED36: LED_y; LED3mm; not fitted
LED37: LED_h; LED3mm; not fitted
LED38: LED_7; LED3mm; not fitted
LED39: LED_n; LED3mm; not fitted
LED40: LED_f6; LED3mm; not fitted
LED41: LED_u; LED3mm; not fitted
LED42: LED_j; LED3mm; not fitted
LED43: LED_8; LED3mm; not fitted
LED44: LED_m; LED3mm; not fitted
LED45: LED_f7; LED3mm; not fitted
LED46: LED_i; LED3mm; not fitted
LED47: LED_k; LED3mm; not fitted
LED48: LED_9; LED3mm; not fitted
LED49: LED_comma; LED3mm; not fitted
LED50: LED_f8; LED3mm; not fitted
LED51: LED_o; LED3mm; not fitted
LED52: LED_l; LED3mm; not fitted
LED53: LED_0; LED3mm; not fitted
LED54: LED_altgr; LED3mm; not fitted
LED55: LED_dot; LED3mm; not fitted
LED56: LED_p; LED3mm; not fitted
LED57: LED_semicolon; LED3mm; not fitted
LED58: LED_f9; LED3mm; not fitted
LED59: LED_minus; LED3mm; not fitted
LED60: LED_slash; LED3mm; not fitted
LED61: LED_win; LED3mm; not fitted
LED62: LED_openbracket; LED3mm; not fitted
LED63: LED_quote; LED3mm; not fitted
LED64: LED_f10; LED3mm; not fitted
LED65: LED_equals; LED3mm; not fitted
LED66: LED_closebracket; LED3mm; not fitted
LED67: LED_menu; LED3mm; not fitted
LED68: LED_f11; LED3mm; not fitted
LED69: LED_rightshift; LED3mm; not fitted
LED70: LED_enter; LED3mm; not fitted
LED71: LED_backspace; LED3mm; not fitted
LED72: LED_backslash; LED3mm; not fitted
LED73: LED_rightcontrol; LED3mm; not fitted
LED74: LED_f12; LED3mm; not fitted
LED75: LED_printscreen; LED3mm; not fitted
LED76: LED_insert; LED3mm; not fitted
LED77: LED_delete; LED3mm; not fitted
LED78: LED_left; LED3mm; not fitted
LED79: LED_scrollock; LED3mm; not fitted
LED80: LED_home; LED3mm; not fitted
LED81: LED_end; LED3mm; not fitted
LED82: LED_up; LED3mm; not fitted
LED83: LED_down; LED3mm; not fitted
LED84: LED_pause; LED3mm; not fitted
LED85: LED_pageup; LED3mm; not fitted
LED86: LED_pagedown; LED3mm; not fitted
LED87: LED_right; LED3mm; not fitted
R5: REXT_0; R_0402_1005Metric; LCSC C25905
R6: REXT_1; R_0402_1005Metric; LCSC C25905
R7: REXT_2; R_0402_1005Metric; LCSC C25905
R8: REXT_3; R_0402_1005Metric; LCSC C25905
R9: REXT_4; R_0402_1005Metric; LCSC C25905
R10: REXT_5; R_0402_1005Metric; LCSC C25905
R11: REXT_6; R_0402_1005Metric; LCSC C25905
R12: REXT_7; R_0402_1005Metric; LCSC C25905
R13: REXT_8; R_0402_1005Metric; LCSC C25905
R14: REXT_9; R_0402_1005Metric; LCSC C25905
R15: REXT_10; R_0402_1005Metric; LCSC C25905
U4: TLC5916_0; TSSOP-16_4.4x5mm_P0.65mm; LCSC C2678539
U5: TLC5916_1; TSSOP-16_4.4x5mm_P0.65mm; LCSC C2678539
U6: TLC5916_2; TSSOP-16_4.4x5mm_P0.65mm; LCSC C2678539
U7: TLC5916_3; TSSOP-16_4.4x5mm_P0.65mm; LCSC C2678539
U8: TLC5916_4; TSSOP-16_4.4x5mm_P0.65mm; LCSC C2678539
U9: TLC5916_5; TSSOP-16_4.4x5mm_P0.65mm; LCSC C2678539
U10: TLC5916_6; TSSOP-16_4.4x5mm_P0.65mm; LCSC C2678539
U11: TLC5916_7; TSSOP-16_4.4x5mm_P0.65mm; LCSC C2678539
U12: TLC5916_8; TSSOP-16_4.4x5mm_P0.65mm; LCSC C2678539
U13: TLC5916_9; TSSOP-16_4.4x5mm_P0.65mm; LCSC C2678539
U14: TLC5916_10; TSSOP-16_4.4x5mm_P0.65mm; LCSC C2678539

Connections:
3V3: C6.1, C7.1, C8.1, C9.1, C11.1, C12.1, C13.1, C14.1, C15.1, C16.1, C17.1, U4.16 (VDD), U5.16 (VDD), U6.16 (VDD), U7.16 (VDD), U8.16 (VDD), U9.16 (VDD), U10.16 (VDD), U11.16 (VDD), U12.16 (VDD), U13.16 (VDD), U14.16 (VDD); also elsewhere on the board
5V: LED1.2 (A), LED2.2 (A), LED3.2 (A), LED4.2 (A), LED5.2 (A), LED6.2 (A), LED7.2 (A), LED8.2 (A), LED9.2 (A), LED10.2 (A), LED11.2 (A), LED12.2 (A), LED13.2 (A), LED14.2 (A), LED15.2 (A), LED16.2 (A), LED17.2 (A), LED18.2 (A), LED19.2 (A), LED20.2 (A), LED21.2 (A), LED22.2 (A), LED23.2 (A), LED24.2 (A), LED25.2 (A), LED26.2 (A), LED27.2 (A), LED28.2 (A), LED29.2 (A), LED30.2 (A), LED31.2 (A), LED32.2 (A), LED33.2 (A), LED34.2 (A), LED35.2 (A), LED36.2 (A), LED37.2 (A), LED38.2 (A), LED39.2 (A), LED40.2 (A), LED41.2 (A), LED42.2 (A), LED43.2 (A), LED44.2 (A), LED45.2 (A), LED46.2 (A), LED47.2 (A), LED48.2 (A), LED49.2 (A), LED50.2 (A), LED51.2 (A), LED52.2 (A), LED53.2 (A), LED54.2 (A), LED55.2 (A), LED56.2 (A), LED57.2 (A), LED58.2 (A), LED59.2 (A), LED60.2 (A), LED61.2 (A), LED62.2 (A), LED63.2 (A), LED64.2 (A), LED65.2 (A), LED66.2 (A), LED67.2 (A), LED68.2 (A), LED69.2 (A), LED70.2 (A), LED71.2 (A), LED72.2 (A), LED73.2 (A), LED74.2 (A), LED75.2 (A), LED76.2 (A), LED77.2 (A), LED78.2 (A), LED79.2 (A), LED80.2 (A), LED81.2 (A), LED82.2 (A), LED83.2 (A), LED84.2 (A), LED85.2 (A), LED86.2 (A), LED87.2 (A); also elsewhere on the board
/LEDs/clk: U4.3 (CLK), U5.3 (CLK), U6.3 (CLK), U7.3 (CLK), U8.3 (CLK), U9.3 (CLK), U10.3 (CLK), U11.3 (CLK), U12.3 (CLK), U13.3 (CLK), U14.3 (CLK); also elsewhere on the board
/LEDs/data_left: U4.2 (SDI); also elsewhere on the board
/LEDs/data_out0: U4.14 (SDO), U5.2 (SDI)
/LEDs/data_out1: U5.14 (SDO), U6.2 (SDI)
/LEDs/data_out2: U6.14 (SDO), U7.2 (SDI)
/LEDs/data_out3: U7.14 (SDO), U8.2 (SDI)
/LEDs/data_out4: U8.14 (SDO), U9.2 (SDI)
/LEDs/data_out5: U9.14 (SDO), U10.2 (SDI)
/LEDs/data_out6: U10.14 (SDO)
/LEDs/data_out7: U11.14 (SDO), U12.2 (SDI)
/LEDs/data_out8: U12.14 (SDO), U13.2 (SDI)
/LEDs/data_out9: U13.14 (SDO), U14.2 (SDI)
/LEDs/data_out10: U14.14 (SDO)
/LEDs/data_right: U11.2 (SDI); also elsewhere on the board
/LEDs/drv_0_a: U4.5 (~OUT0)
/LEDs/latch: U4.4 (LE(ED1)), U5.4 (LE(ED1)), U6.4 (LE(ED1)), U7.4 (LE(ED1)), U8.4 (LE(ED1)), U9.4 (LE(ED1)), U10.4 (LE(ED1)), U11.4 (LE(ED1)), U12.4 (LE(ED1)), U13.4 (LE(ED1)), U14.4 (LE(ED1)); also elsewhere on the board
/LEDs/led_0: LED53.1 (K), U11.9 (~OUT4)
/LEDs/led_1: LED7.1 (K), U9.9 (~OUT4)
/LEDs/led_2: LED12.1 (K), U8.10 (~OUT5)
/LEDs/led_3: LED18.1 (K), U8.7 (~OUT2)
/LEDs/led_4: LED23.1 (K), U7.9 (~OUT4)
/LEDs/led_5: LED28.1 (K), U6.11 (~OUT6)
/LEDs/led_6: LED32.1 (K), U6.6 (~OUT1)
/LEDs/led_7: LED38.1 (K), U5.10 (~OUT5)
/LEDs/led_8: LED43.1 (K), U4.11 (~OUT6)
/LEDs/led_9: LED48.1 (K), U4.8 (~OUT3)
/LEDs/led_a: LED10.1 (K), U9.11 (~OUT6)
/LEDs/led_alt: LED15.1 (K), U9.5 (~OUT0)
/LEDs/led_altgr: LED54.1 (K), U5.9 (~OUT4)
/LEDs/led_b: LED33.1 (K), U7.6 (~OUT1)
/LEDs/led_backslash: LED72.1 (K), U13.11 (~OUT6)
/LEDs/led_backspace: LED71.1 (K), U13.10 (~OUT5)
/LEDs/led_c: LED24.1 (K), U8.9 (~OUT4)
/LEDs/led_capslock: LED5.1 (K), U10.10 (~OUT5)
/LEDs/led_closebracket: LED66.1 (K), U12.7 (~OUT2)
/LEDs/led_comma: LED49.1 (K), U5.6 (~OUT1)
/LEDs/led_d: LED21.1 (K), U8.5 (~OUT0)
/LEDs/led_delete: LED77.1 (K), U13.6 (~OUT1)
/LEDs/led_dot: LED55.1 (K), U4.9 (~OUT4)
/LEDs/led_down: LED83.1 (K), U13.8 (~OUT3)
/LEDs/led_e: LED20.1 (K), U8.6 (~OUT1)
/LEDs/led_end: LED81.1 (K), U14.10 (~OUT5)
/LEDs/led_enter: LED70.1 (K), U12.9 (~OUT4)
/LEDs/led_equals: LED65.1 (K), U12.8 (~OUT3)
/LEDs/led_esc: LED1.1 (K), U10.5 (~OUT0)
/LEDs/led_f: LED26.1 (K), U7.11 (~OUT6)
/LEDs/led_f1: LED11.1 (K), U9.12 (~OUT7)
/LEDs/led_f2: LED17.1 (K), U8.12 (~OUT7)
/LEDs/led_f3: LED22.1 (K), U8.11 (~OUT6)
/LEDs/led_f4: LED27.1 (K), U7.12 (~OUT7)
/LEDs/led_f5: LED35.1 (K), U6.12 (~OUT7)
/LEDs/led_f6: LED40.1 (K), U5.12 (~OUT7)
/LEDs/led_f7: LED45.1 (K), U5.5 (~OUT0)
/LEDs/led_f8: LED50.1 (K), U4.12 (~OUT7)
/LEDs/led_f9: LED58.1 (K), U12.12 (~OUT7)
/LEDs/led_f10: LED64.1 (K), U12.6 (~OUT1)
/LEDs/led_f11: LED68.1 (K), U12.5 (~OUT0)
/LEDs/led_f12: LED74.1 (K), U13.12 (~OUT7)
/LEDs/led_fn: LED8.1 (K), U10.8 (~OUT3)
/LEDs/led_g: LED31.1 (K), U7.7 (~OUT2)
/LEDs/led_h: LED37.1 (K), U6.9 (~OUT4)
/LEDs/led_home: LED80.1 (K), U14.9 (~OUT4)
/LEDs/led_i: LED46.1 (K), U5.7 (~OUT2)
/LEDs/led_insert: LED76.1 (K), U14.11 (~OUT6)
/LEDs/led_j: LED42.1 (K), U6.7 (~OUT2)
/LEDs/led_k: LED47.1 (K), U5.8 (~OUT3)
/LEDs/led_l: LED52.1 (K), U4.6 (~OUT1)
/LEDs/led_left: LED78.1 (K), U13.9 (~OUT4)
/LEDs/led_leftcontrol: LED3.1 (K), U10.12 (~OUT7)
/LEDs/led_leftshift: LED6.1 (K), U10.11 (~OUT6)
/LEDs/led_m: LED44.1 (K), U6.8 (~OUT3)
/LEDs/led_menu: LED67.1 (K), U11.8 (~OUT3)
/LEDs/led_minus: LED59.1 (K), U11.5 (~OUT0)
/LEDs/led_n: LED39.1 (K), U6.10 (~OUT5)
/LEDs/led_o: LED51.1 (K), U4.7 (~OUT2)
/LEDs/led_openbracket: LED62.1 (K), U11.6 (~OUT1)
/LEDs/led_p: LED56.1 (K), U11.10 (~OUT5)
/LEDs/led_pagedown: LED86.1 (K), U14.7 (~OUT2)
/LEDs/led_pageup: LED85.1 (K), U14.6 (~OUT1)
/LEDs/led_pause: LED84.1 (K), U14.5 (~OUT0)
/LEDs/led_printscreen: LED75.1 (K), U13.5 (~OUT0)
/LEDs/led_q: LED9.1 (K), U9.10 (~OUT5)
/LEDs/led_quote: LED63.1 (K), U11.7 (~OUT2)
/LEDs/led_r: LED25.1 (K), U7.10 (~OUT5)
/LEDs/led_right: LED87.1 (K), U14.8 (~OUT3)
/LEDs/led_rightcontrol: LED73.1 (K), U12.11 (~OUT6)
/LEDs/led_rightshift: LED69.1 (K), U12.10 (~OUT5)
/LEDs/led_s: LED16.1 (K), U9.7 (~OUT2)
/LEDs/led_scrollock: LED79.1 (K), U14.12 (~OUT7)
/LEDs/led_semicolon: LED57.1 (K), U11.11 (~OUT6)
/LEDs/led_slash: LED60.1 (K), U11.12 (~OUT7)
/LEDs/led_space: LED34.1 (K), U7.5 (~OUT0)
/LEDs/led_t: LED30.1 (K), U7.8 (~OUT3)
/LEDs/led_tab: LED4.1 (K), U10.9 (~OUT4)
/LEDs/led_tilde: LED2.1 (K), U10.6 (~OUT1)
/LEDs/led_u: LED41.1 (K), U5.11 (~OUT6)
/LEDs/led_up: LED82.1 (K), U13.7 (~OUT2)
/LEDs/led_v: LED29.1 (K), U8.8 (~OUT3)
/LEDs/led_w: LED14.1 (K), U9.8 (~OUT3)
/LEDs/led_win: LED61.1 (K), U4.10 (~OUT5)
/LEDs/led_x: LED19.1 (K), U9.6 (~OUT1)
/LEDs/led_y: LED36.1 (K), U6.5 (~OUT0)
/LEDs/led_z: LED13.1 (K), U10.7 (~OUT2)
/LEDs/oe: U4.13 (~OE(ED2)), U5.13 (~OE(ED2)), U6.13 (~OE(ED2)), U7.13 (~OE(ED2)), U8.13 (~OE(ED2)), U9.13 (~OE(ED2)), U10.13 (~OE(ED2)), U11.13 (~OE(ED2)), U12.13 (~OE(ED2)), U13.13 (~OE(ED2)), U14.13 (~OE(ED2)); also elsewhere on the board
GND: C6.2, C7.2, C8.2, C9.2, C11.2, C12.2, C13.2, C14.2, C15.2, C16.2, C17.2, R5.2, R6.2, R7.2, R8.2, R9.2, R10.2, R11.2, R12.2, R13.2, R14.2, R15.2, U4.1 (GND), U5.1 (GND), U6.1 (GND), U7.1 (GND), U8.1 (GND), U9.1 (GND), U10.1 (GND), U11.1 (GND), U12.1 (GND), U13.1 (GND), U14.1 (GND); also elsewhere on the board
unnamed: R5.1, U4.15 (R-EXT)
unnamed: R6.1, U5.15 (R-EXT)
unnamed: R7.1, U6.15 (R-EXT)
unnamed: R8.1, U7.15 (R-EXT)
unnamed: R9.1, U8.15 (R-EXT)
unnamed: R10.1, U9.15 (R-EXT)
unnamed: R11.1, U10.15 (R-EXT)
unnamed: R12.1, U11.15 (R-EXT)
unnamed: R13.1, U12.15 (R-EXT)
unnamed: R14.1, U13.15 (R-EXT)
unnamed: R15.1, U14.15 (R-EXT)

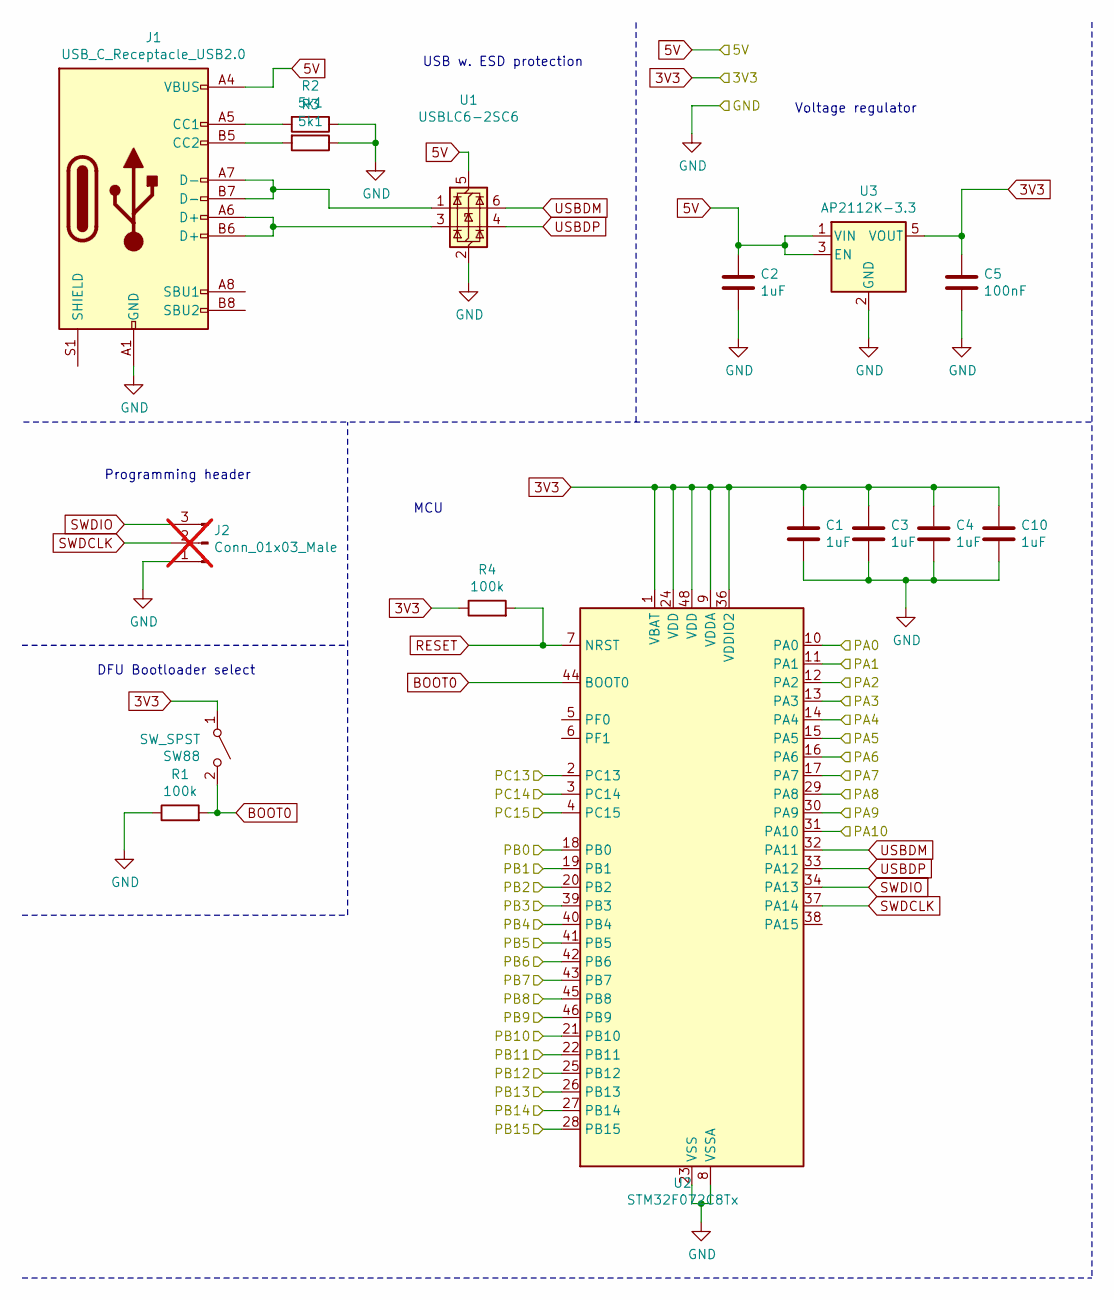
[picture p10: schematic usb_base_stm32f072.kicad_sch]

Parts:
C1, C2, C3, C4, C10: 1uF; C_0402_1005Metric; LCSC C52923
C5: 100nF; C_0402_1005Metric; LCSC C1525
J1: USB_C_Receptacle_USB2.0; USB_C_Receptacle_HRO_TYPE-C-31-M-12; LCSC C165948
J2: Conn_01x03_Male; PinHeader_1x03_P2.54mm_Vertical; not fitted
R1, R4: 100k; R_0402_1005Metric; LCSC C25741
R2, R3: 5k1; R_0402_1005Metric; LCSC C25905
SW88: SW_SPST; SW_Push_1P1T_NO_CK_KMR2; LCSC C318893
U1: USBLC6-2SC6; SOT-23-6; LCSC C7519
U2: STM32F072C8Tx; LQFP-48_7x7mm_P0.5mm; LCSC C81720
U3: AP2112K-3.3; SOT-23-5; LCSC C51118

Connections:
3V3: C1.1, C3.1, C4.1, C5.1, C10.1, R4.1, SW88.1 (A), U2.1 (VBAT), U2.9 (VDDA), U2.24 (VDD), U2.36 (VDDIO2), U2.48 (VDD), U3.5 (VOUT); also elsewhere on the board
5V: C2.1, J1.A4 (VBUS), J1.A9 (VBUS), J1.B4 (VBUS), J1.B9 (VBUS), U1.5 (VBUS), U3.1 (VIN), U3.3 (EN); also elsewhere on the board
/C0: U2.28 (PB15); also elsewhere on the board
/C1: U2.27 (PB14); also elsewhere on the board
/C2: U2.26 (PB13); also elsewhere on the board
/C3: U2.25 (PB12); also elsewhere on the board
/C4: U2.22 (PB11); also elsewhere on the board
/C5: U2.21 (PB10); also elsewhere on the board
/C6: U2.20 (PB2); also elsewhere on the board
/C7: U2.19 (PB1); also elsewhere on the board
/C8: U2.18 (PB0); also elsewhere on the board
/C9: U2.42 (PB6); also elsewhere on the board
/C10: U2.46 (PB9); also elsewhere on the board
/C11: U2.45 (PB8); also elsewhere on the board
/C12: U2.43 (PB7); also elsewhere on the board
/C13: U2.41 (PB5); also elsewhere on the board
/C14: U2.40 (PB4); also elsewhere on the board
/C15: U2.39 (PB3); also elsewhere on the board
/LEDs/clk: U2.3 (PC14); also elsewhere on the board
/LEDs/data_left: U2.4 (PC15); also elsewhere on the board
/LEDs/data_right: U2.2 (PC13); also elsewhere on the board
/LEDs/latch: U2.10 (PA0); also elsewhere on the board
/LEDs/oe: U2.11 (PA1); also elsewhere on the board
/R0: U2.17 (PA7); also elsewhere on the board
/R1: U2.12 (PA2); also elsewhere on the board
/R2: U2.13 (PA3); also elsewhere on the board
/R3: U2.14 (PA4); also elsewhere on the board
/R4: U2.15 (PA5); also elsewhere on the board
/R5: U2.16 (PA6); also elsewhere on the board
/usb_base/PA8: U2.29 (PA8)
/usb_base/PA9: U2.30 (PA9)
/usb_base/PA10: U2.31 (PA10)
BOOT0: R1.2, SW88.2 (B), U2.44 (BOOT0)
GND: C1.2, C2.2, C3.2, C4.2, C5.2, C10.2, J1.A1 (GND), J1.A12 (GND), J1.B1 (GND), J1.B12 (GND), J2.1, R1.1, R2.1, R3.1, U1.2 (GND), U2.8 (VSSA), U2.23 (VSS), U2.35 (VSS), U2.47 (VSS), U3.2 (GND); also elsewhere on the board
unnamed: J1.A5 (CC1), R2.2
unnamed: J1.B5 (CC2), R3.2
unnamed: J1.A6 (D+), J1.B6 (D+), U1.3 (I/O2)
unnamed: J1.A7 (D-), J1.B7 (D-), U1.1 (I/O1)
RESET: R4.2, U2.7 (NRST)
SWDCLK: J2.2, U2.37 (PA14)
SWDIO: J2.3, U2.34 (PA13)
USBDM: U1.6 (I/O1), U2.32 (PA11)
USBDP: U1.4 (I/O2), U2.33 (PA12)

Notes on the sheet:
Programming header
DFU Bootloader select
Voltage regulator
MCU
USB w. ESD protection

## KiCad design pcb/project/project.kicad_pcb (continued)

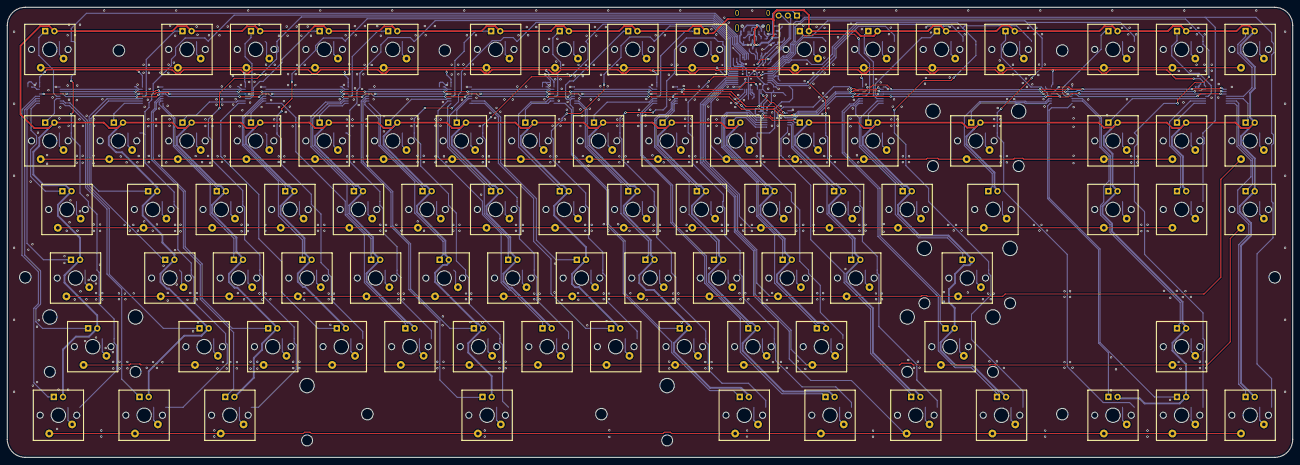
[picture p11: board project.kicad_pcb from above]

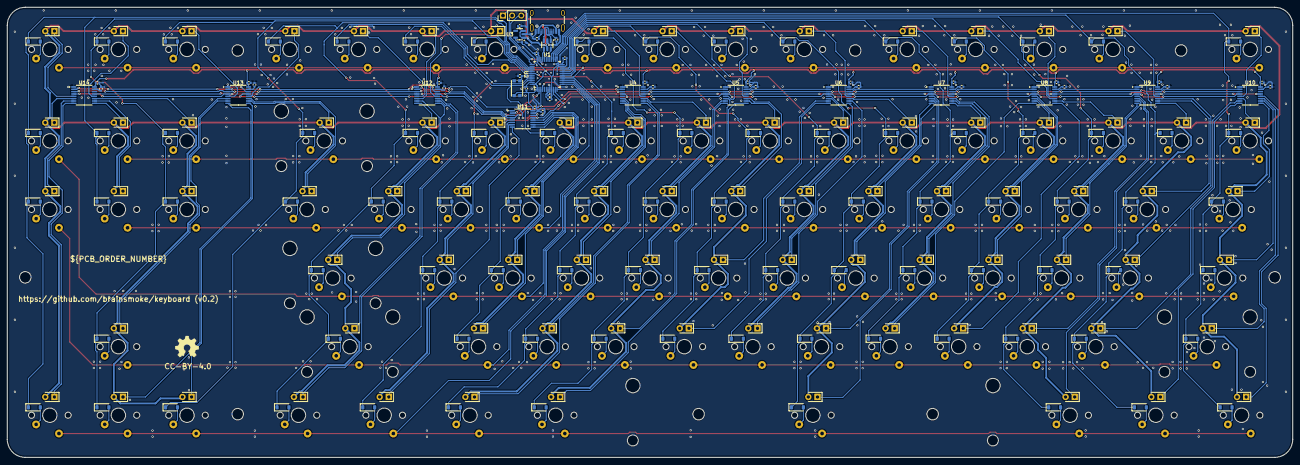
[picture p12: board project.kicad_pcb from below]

Board: 2 copper layers, 357.0 x 125.0 mm, 310 parts (223 on the bottom side), 234 nets.

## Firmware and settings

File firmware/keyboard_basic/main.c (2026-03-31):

/*
 * Copyright (c) 2026 Erik Bosman <erik@minemu.org>
 *
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
 * (http://opensource.org/licenses/mit-license.html)
 *
 */

#include <stdint.h>
#include <string.h>

#include <libopencmsis/core_cm3.h>

#include <libopencm3/stm32/rcc.h>

#include "config.h"
#include "util.h"
#include "millis.h"
#include "usb_hid_keyboard.h"
#include "keyboard_leds.h"
#include "codegen_header.h"
#include "keymatrix.h"

#include "codegen_tables.c"

static uint8_t fb[N_LEDS];

#define HID_CODES(a,b) (b),
static const uint32_t extra_keys[] = { FN_ALTERNATIVES(HID_CODES) };
#undef HID_CODES

#define BACKLIGHT_MIN_STATE (0)
#define BACKLIGHT_MAX_STATE (2)

static const struct
{
	uint8_t normal;
	uint8_t on;
} color_table[BACKLIGHT_MAX_STATE+1] = 
{
	{0x00, 0xff},
	{0x3f, 0xff},
	{0x7f, 0xff},
};

static uint8_t backlight_state = BACKLIGHT_MIN_STATE;

static const uint32_t alt_keymap[KEYMATRIX_N_KEYS] =
{
#define MAPPING(a,b) [a] = b,
	FN_ALTERNATIVES(MAPPING)
#undef MAPPING
	[MATRIX_leftshift]    = KEYCODE_leftshift,
	[MATRIX_rightshift]   = KEYCODE_rightshift,
	[MATRIX_leftcontrol]  = KEYCODE_leftcontrol,
	[MATRIX_alt]          = KEYCODE_alt,
	[MATRIX_altgr]        = KEYCODE_altgr,
	[MATRIX_win]          = KEYCODE_win,
	[MATRIX_menu]         = KEYCODE_menu,
	[MATRIX_rightcontrol] = KEYCODE_rightcontrol,
};

static uint8_t fn_pressed = 0;
static uint8_t fn_lock = 0;
static uint8_t caps_lock_on = 0;
static uint8_t scroll_lock_on = 0;

static void set_backlight(uint8_t state)
{
	uint8_t normal = color_table[state].normal,
	        on     = color_table[state].on;

	memset(fb, normal, sizeof(fb));
	fb[LED_capslock] = caps_lock_on ? on : normal;
	fb[LED_scrollock] = scroll_lock_on ? on : normal;
	fb[LED_esc] = fn_lock ? on : normal;

	write_frame(fb);
}

static void change_backlight(void)
{
	if (backlight_state >= BACKLIGHT_MAX_STATE)
		backlight_state =  BACKLIGHT_MIN_STATE;
	else
		backlight_state += 1;

	set_backlight(backlight_state);
}

/* callback: defined in usb_hid_keyboard.h */
void usb_hid_keyboard_led_state(uint8_t led_state)
{
	caps_lock_on = (led_state & HID_REPORT_LED_CAPS_LOCK) ? 1:0;
	scroll_lock_on = (led_state & HID_REPORT_LED_SCROLL_LOCK) ? 1:0;
	set_backlight(backlight_state);
}

/* callback: defined in keymatrix.h */
void keymatrix_down(int key)
{
	if (key == MATRIX_fn)
	{
		usb_hid_keyboard_clear_keys(); /* does not clear modifier keys */
		fn_pressed = 1;
		return;
	}

	if (fn_pressed)
	{
		if (key == MATRIX_esc)
		{
			fn_lock = !fn_lock;
			set_backlight(backlight_state);
			return;
		}
		else if (key == MATRIX_space)
		{
			change_backlight();
			return;
		}
	}

	int use_alt = fn_pressed;
	if (fn_lock && alt_keymap[key])
		use_alt = !use_alt;

	uint32_t hid_key = (use_alt ? alt_keymap : matrix_to_keycode)[key];

	if (hid_key != KEY_NONE)
		usb_hid_keyboard_key_down( hid_key );
}

/* callback: defined in keymatrix.h */
void keymatrix_up(int key)
{
	if (key == MATRIX_fn)
	{
		fn_pressed = 0;
		return;
	}

	uint32_t hid_key = matrix_to_keycode[key];

	if (hid_key != KEY_NONE)
		usb_hid_keyboard_key_up(hid_key);

	hid_key = alt_keymap[key];
	if (hid_key != KEY_NONE)
		usb_hid_keyboard_key_up(hid_key);
}

static void init(void)
{
	rcc_clock_setup_in_hsi_out_48mhz();
	rcc_periph_clock_enable(RCC_GPIOA);
	rcc_periph_clock_enable(RCC_GPIOB);
	rcc_periph_clock_enable(RCC_GPIOC);

	usb_hid_keyboard_init(extra_keys, sizeof(extra_keys)/sizeof(extra_keys[0]));

	millis_timer_init();

	init_leds();
	set_backlight(backlight_state);
	keymatrix_init();
}

int main(void)
{
	init();

	for(;;)
	{
		keymatrix_poll(millis());
		usb_hid_keyboard_poll();
	}
}

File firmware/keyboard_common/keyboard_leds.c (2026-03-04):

#include <stdlib.h>
#include <string.h>

#include "keyboard_leds.h"
#include "util.h"
#include "millis.h"

typedef struct __attribute__((packed,aligned(4)))
{
	uint8_t bit[16][MAX_BITS_PER_CHANNEL]; 
} frame_t;

frame_t frame_a, frame_b;

static frame_t * volatile cur_frame;
static frame_t * volatile next_frame;
static frame_t * volatile draw_frame;

static uint16_t iter;

enum
{
	B15, B14, B13, B12, B11, B10, B9, B8,
	B7, B6, B5, B4, B3, B2, B1, B0,
	E0, E1, E2, E3, E4, E5, E6, E7, E8,
	ZZZ,
};

/* SysTick dispatch table for BCM bitbang */
static const uint8_t dtable[] =
{
/*	 15    .    .    .    .    .    .    .   14    .    .    .   13    .   12  11/10 dith */

	B15, ZZZ, ZZZ, ZZZ, ZZZ, ZZZ, ZZZ, ZZZ, B14, ZZZ, ZZZ, ZZZ, B13, ZZZ, B12, B11,  B8, E8,
	B15, ZZZ, ZZZ, ZZZ, ZZZ, ZZZ, ZZZ, ZZZ, B14, ZZZ, ZZZ, ZZZ, B13, ZZZ, B12, B10,  B4, E4,
	B15, ZZZ, ZZZ, ZZZ, ZZZ, ZZZ, ZZZ, ZZZ, B14, ZZZ, ZZZ, ZZZ, B13, ZZZ, B12, B11,  B6, E6,
	B15, ZZZ, ZZZ, ZZZ, ZZZ, ZZZ, ZZZ, ZZZ, B14, ZZZ, ZZZ, ZZZ, B13, ZZZ, B12,  B9,  B2, E2,

	B15, ZZZ, ZZZ, ZZZ, ZZZ, ZZZ, ZZZ, ZZZ, B14, ZZZ, ZZZ, ZZZ, B13, ZZZ, B12, B11,  B7, E7,
	B15, ZZZ, ZZZ, ZZZ, ZZZ, ZZZ, ZZZ, ZZZ, B14, ZZZ, ZZZ, ZZZ, B13, ZZZ, B12, B10,  B3, E3,
	B15, ZZZ, ZZZ, ZZZ, ZZZ, ZZZ, ZZZ, ZZZ, B14, ZZZ, ZZZ, ZZZ, B13, ZZZ, B12, B11,  B5, E5,
	B15, ZZZ, ZZZ, ZZZ, ZZZ, ZZZ, ZZZ, ZZZ, B14, ZZZ, ZZZ, ZZZ, B13, ZZZ, B12,       B1, E2,

	B15, ZZZ, ZZZ, ZZZ, ZZZ, ZZZ, ZZZ, ZZZ, B14, ZZZ, ZZZ, ZZZ, B13, ZZZ, B12, B11,  B8, E8,
	B15, ZZZ, ZZZ, ZZZ, ZZZ, ZZZ, ZZZ, ZZZ, B14, ZZZ, ZZZ, ZZZ, B13, ZZZ, B12, B10,  B4, E4,
	B15, ZZZ, ZZZ, ZZZ, ZZZ, ZZZ, ZZZ, ZZZ, B14, ZZZ, ZZZ, ZZZ, B13, ZZZ, B12, B11,  B6, E6,
	B15, ZZZ, ZZZ, ZZZ, ZZZ, ZZZ, ZZZ, ZZZ, B14, ZZZ, ZZZ, ZZZ, B13, ZZZ, B12,  B9,  B2, E2,

	B15, ZZZ, ZZZ, ZZZ, ZZZ, ZZZ, ZZZ, ZZZ, B14, ZZZ, ZZZ, ZZZ, B13, ZZZ, B12, B11,  B7, E7,
	B15, ZZZ, ZZZ, ZZZ, ZZZ, ZZZ, ZZZ, ZZZ, B14, ZZZ, ZZZ, ZZZ, B13, ZZZ, B12, B10,  B3, E3,
	B15, ZZZ, ZZZ, ZZZ, ZZZ, ZZZ, ZZZ, ZZZ, B14, ZZZ, ZZZ, ZZZ, B13, ZZZ, B12, B11,  B5, E5,
	B15, ZZZ, ZZZ, ZZZ, ZZZ, ZZZ, ZZZ, ZZZ, B14, ZZZ, ZZZ, ZZZ, B13, ZZZ, B12,       B0, E1,

};

#define TABLE_SIZE (sizeof(dtable)/sizeof(dtable[0]))

static void bitbang_15(void) { bitbang_56bits_stm32(cur_frame->bit[15], (void *)GPIO_LEDS_DATA, (void *)GPIO_LEDS_LATCH, 0); draw_frame = cur_frame; }
static void bitbang_14(void) { bitbang_56bits_stm32(draw_frame->bit[14], (void *)GPIO_LEDS_DATA, (void *)GPIO_LEDS_LATCH, 0); }
static void bitbang_13(void) { bitbang_56bits_stm32(draw_frame->bit[13], (void *)GPIO_LEDS_DATA, (void *)GPIO_LEDS_LATCH, 0); }
static void bitbang_12(void) { bitbang_56bits_stm32(draw_frame->bit[12], (void *)GPIO_LEDS_DATA, (void *)GPIO_LEDS_LATCH, 0); }
static void bitbang_11(void) { bitbang_56bits_stm32(draw_frame->bit[11], (void *)GPIO_LEDS_DATA, (void *)GPIO_LEDS_LATCH, 0); }
static void bitbang_10(void) { bitbang_56bits_stm32(draw_frame->bit[10], (void *)GPIO_LEDS_DATA, (void *)GPIO_LEDS_LATCH, 0); }
static void bitbang_9(void)  { bitbang_56bits_stm32(draw_frame->bit[ 9], (void *)GPIO_LEDS_DATA, (void *)GPIO_LEDS_LATCH, 0); }

static void bitbang_8(void)  { bitbang_56bits_stm32(draw_frame->bit[ 8], (void *)GPIO_LEDS_DATA, (void *)GPIO_LEDS_LATCH, BIT_NOT_OUTPUT_ENABLE); }
static void bitbang_7(void)  { bitbang_56bits_stm32(draw_frame->bit[ 7], (void *)GPIO_LEDS_DATA, (void *)GPIO_LEDS_LATCH, BIT_NOT_OUTPUT_ENABLE); }
static void bitbang_6(void)  { bitbang_56bits_stm32(draw_frame->bit[ 6], (void *)GPIO_LEDS_DATA, (void *)GPIO_LEDS_LATCH, BIT_NOT_OUTPUT_ENABLE); }
static void bitbang_5(void)  { bitbang_56bits_stm32(draw_frame->bit[ 5], (void *)GPIO_LEDS_DATA, (void *)GPIO_LEDS_LATCH, BIT_NOT_OUTPUT_ENABLE); }
static void bitbang_4(void)  { bitbang_56bits_stm32(draw_frame->bit[ 4], (void *)GPIO_LEDS_DATA, (void *)GPIO_LEDS_LATCH, BIT_NOT_OUTPUT_ENABLE); }
static void bitbang_3(void)  { bitbang_56bits_stm32(draw_frame->bit[ 3], (void *)GPIO_LEDS_DATA, (void *)GPIO_LEDS_LATCH, BIT_NOT_OUTPUT_ENABLE); }
static void bitbang_2(void)  { bitbang_56bits_stm32(draw_frame->bit[ 2], (void *)GPIO_LEDS_DATA, (void *)GPIO_LEDS_LATCH, BIT_NOT_OUTPUT_ENABLE); }
static void bitbang_1(void)  { bitbang_56bits_stm32(draw_frame->bit[ 1], (void *)GPIO_LEDS_DATA, (void *)GPIO_LEDS_LATCH, BIT_NOT_OUTPUT_ENABLE); }
static void bitbang_0(void)  { bitbang_56bits_stm32(draw_frame->bit[ 0], (void *)GPIO_LEDS_DATA, (void *)GPIO_LEDS_LATCH, BIT_NOT_OUTPUT_ENABLE); }

#define FLIP_OFF (SET(BIT_NOT_OUTPUT_ENABLE))
#define FLIP_ON  (CLEAR(BIT_NOT_OUTPUT_ENABLE))
#define SYSTICK_PERIOD ((uint32_t)(F_SYS_TICK_CLK/(TABLE_SIZE*200) ))
#define SYSTICK_CYCLES ((uint32_t)(8*SYSTICK_PERIOD))
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

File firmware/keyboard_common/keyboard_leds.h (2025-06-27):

#ifndef BITBANG_H
#define BITBANG_H

/* platform constants */

#define GPIO_ODR_OFFSET (0x14)
#define GPIO_BSRR_OFFSET (0x18)
#define GPIO_BRR_OFFSET (0x28)

/* GPIO, BSRR */

#define CLEAR(X) (X<<16)
#define SET(X)   (X)

/* GPIO C */
#define PIN_DATA_LEFT          (15)
#define PIN_DATA_RIGHT         (13)
#define PIN_CLK                (14)

/* GPIO A */
#define PIN_LATCH              (0)
#define PIN_NOT_OUTPUT_ENABLE  (1)


#define BIT_DATA_LEFT          (1<<PIN_DATA_LEFT)
#define BIT_DATA_RIGHT         (1<<PIN_DATA_RIGHT)
#define BIT_CLK                (1<<PIN_CLK)
#define BIT_LATCH              (1<<PIN_LATCH)
#define BIT_NOT_OUTPUT_ENABLE  (1<<PIN_NOT_OUTPUT_ENABLE)

#define MASK_CLK (BIT_CLK)
#define MASK_DATA (BIT_DATA_LEFT|BIT_DATA_RIGHT)

#ifndef __ASSEMBLER__

#include <stdint.h>
#include "config.h"

#define GPIO_LEDS_DATA (GPIOC)
#define GPIO_LEDS_LATCH (GPIOA)

#define BUFFER_BIT_DATA_LEFT (BIT_DATA_LEFT>>8)
#define BUFFER_BIT_DATA_RIGHT (BIT_DATA_RIGHT>>8)

#define N_LEDS (88) /* one driver output is not connected */
#define N_CHANNELS (2)
#define MAX_BITS_PER_CHANNEL (56)
#define CHANNEL_PIN { BUFFER_BIT_DATA_LEFT, BUFFER_BIT_DATA_RIGHT }
#define CHANNEL_START { 0, MAX_BITS_PER_CHANNEL-32 }

/* sends 56x bits parallel at 1/8th the clockspeed
 * gpio is the GPIO base address
 * 
 * probably close to 500 cycles including call
 */
void bitbang_56bits_stm32(uint8_t *buffer, volatile uint32_t *gpio_data_clock, volatile uint32_t *gpio_latch_enable, uint32_t not_enable_mask);
void write_wait_write(volatile uint32_t *addr, uint32_t pre_data, uint32_t post_data, uint32_t cycles);

void init_leds(void);
void write_frame(uint8_t fb[N_LEDS]);

#endif

#endif // BITBANG_H

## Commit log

2025-05-30 generate schematic
    [keys.kicad_sch, project.kicad_pcb, project.kicad_sch]
2025-05-31 board positioning
    [keys.kicad_sch, project.kicad_pcb, project.kicad_sch]
2025-06-07 routing done
    [keys.kicad_sch, leds.kicad_sch, project.kicad_sch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]
2025-06-19 fixed the slots in the USB-C footprint, no clue how they got changed
2025-06-26 reorg pcb/schematice generator scripts
2025-06-26 initial led driver code
2025-06-27 clean up leds test
2025-06-30 rename sheet labels to port names
    [project.kicad_sch, usb_base_stm32f072.kicad_sch]
2026-02-15 add footprints
2026-02-26 fix led mapping
2026-02-26 fix led distance table
2026-03-12 move/unify backlight leds bitbang routine
2026-03-21 add laser cut 'case'
2026-03-24 add 'case'
    [feet.scad, feet_print_right_side_up.scad, feet_print_right_side_up.stl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]
2026-03-27 add some more non-plated holes for version 0.2
    [project.kicad_pcb]
2026-04-01 automate pcba production files [untested]
    [bomfile_jlc.csv, keys.kicad_sch, leds.kicad_sch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]
2026-04-01 do correction processing in kicad coordinates
2026-04-06 tweak 3d-printed drill holes
    [feet.scad, feet_print_right_side_up.stl, feet_upside_down.stl]
2026-04-07 add extra holes to case (for v2)
2026-04-21 fix problems with lastercut case
2026-04-29 add lasercut 'case'

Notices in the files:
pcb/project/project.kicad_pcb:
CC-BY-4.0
